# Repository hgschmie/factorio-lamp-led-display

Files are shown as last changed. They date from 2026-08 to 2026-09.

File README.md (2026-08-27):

# Factorio Lamp LED Display

Adds a mod to the Factorio game (2.1 version needed) that sends out UDP packets to a local receiver daemon. The daemon creates MQTT messages that can be picked up by embedded microcontrollers that in turn drive Neopixel LEDs which reflect the color and status of in-game Lamps.

Factorio -> UDP to local receiver -> daemon (golang code) -> MQTT (mosquitto broker) -> ESP32-C3 receiver -> Neopixel LEDs

This repository contains most of the pieces required to build this. You need to bring some skills/tools though:

- at least breadboarding, better soldering for the hardware
- a 3D printer to make the Lamp cases
- a local docker installation on the machine where you run Factorio (or you need to run the daemon manually, it is a single binary)

What you find:

- `daemon` contains the golang code for the local receiver daemon
- `factorio-mod` contains the code for the [Lamp LED Display](https://mods.factorio.com/mod/lamp_led_display) mod. Or get it from the mod portal
- `firmware` contains the software for the ESP32-C3 supermini board
- `pcb` contains the KiCAD files for a controller board. Or you can breadboard this together, either works fine.
- `3dprint` contains the 3MF files for the Lamp.

## How to get it to work

(All of this is intended to be run in a local network that is firewalled/secured against the internet. There is little security besides bare-bones passwords that are written in cleartext in config files locally. If you care deeply about security, there is room for improvement)

### Local setup

This sets up runtime config, broker credentials and starts the daemon.

```sh
cp config.example.yaml config.yaml
./scripts/create-credentials.sh
docker compose up -d --build
```

The `config.yaml` file is read by the daemon on startup. The secrets created by the script are stored in the `secrets` directory.

If everything goes well, this is what docker ps should show:

```text
❯ docker ps
CONTAINER ID   IMAGE                      COMMAND                  CREATED       STATUS       PORTS                                         NAMES
208767bb72bf   display-daemon             "/factorio-display"      6 hours ago   Up 6 hours   127.0.0.1:34198->34198/udp                    display-daemon-1
9c2e8b83e011   eclipse-mosquitto:2.0.22   "/docker-entrypoint.…"   6 hours ago   Up 6 hours   0.0.0.0:1883->1883/tcp, [::]:1883->1883/tcp   display-mosquitto-1
```

### Factorio Setup

- add the mod from the mod portal (or copy the `factorio-mod/lamp_led_display` folder into your mod folder). Add `--enable-lua-udp 34199` to the Factorio start command. If you run Factorio from Steam, you can add this to the "Launch Options" directly in Steam.

- Start Factorio and load a game that has the mod activated. Then run `docker logs -f display-daemon-1` from a command line window. You should see something like this:

```text
daemon-1     | {"time":"2026-08-27T01:00:59.183286626Z","level":"INFO","msg":"factorio packet accepted","save_id":"1f0288b3-4937613a","sequence":1,"type":"snapshot","channels":0}
```

If you see this, congrats, Factorio is talking to the locally running daemon and writes MQTT messages.

### Get some LEDs

Make sure to get an ESP32-C3 supermini board (most other ESP32-C3 boards should work, too).

- Install the PlatformIO framework. On a mac, do `brew install platformio`. Otherwise, go to [PlatformIO Core installation](https://platformio.org/install/cli) and follow the instructions

- connect your board to the computer with an USB cable

- run

```sh
cd firmware
pio run -e esp32-c3-supermini -t upload
pio device monitor
```

If all goes well, you should see a `Factorio-Display-xxxxxx` WiFi network appear. Connect to it (e.g. with a smartphone), it should pop open a capturing portal to enter WiFi credentials, MQTT broker information. Leave the pixel count as "8" and the "channel offset" as 0. Save, reboot and now the device should show (in the shell that does the `pio device monitor`) something like this:

```text
Connected!
*wm:AutoConnect: SUCCESS
*wm:STA IP Address: 172.16.10.102
Configuration page: http://172.16.10.102/ or http://factorio-display-shop-floor-a.local/
```

running `docker logs display-mosquitto-1` should show something like this:

```text
1787807093: New client connected from 192.168.65.1:46373 as factorio-display-shop-floor-a (p2, c1, k30, u'device').
```

### Assign a lamp

If you have any Neopixels connected to the ESP32-C3 chip, you are now ready to assign a lamp to them. If you are not running the game right now, after a few seconds, all LEDs should start to slowly pulse cyan to show that "no Factorio game is sending any information". This also happens when you pause the game.

Put a Lamp down, give it some color, make sure that "always on" is checked.

Press ALT/Option + Shift + D. The cursor should now show a lamp.

Click on the Lamp you just placed. In the dialog, set the Channel Number to "1". PRESS ENTER!

The first LED on your ESP32-C3 should now have the same color as the lamp in the game.

Press Control + Shift + D to open the Channel list where you can control other aspects or delete a channel.

----

## Project background

This project owes its existence to the lucky confluence of a few things.

- I found a Factorio Lamp on Makerworld that is designed for RGB (Neopixel) LEDs.
- I really wanted to play around with ESP32-C3 Supermini boards and I had a few lying around.
- Adafruit sells nice 5mm discrete multi-color LEDs that are Neopixel compatible.

And while all of this is great, some obstacles were in the way:

- The Factorio Lamp was single-color white and not gray/translucent. So some remixing was required.
- Besides 3D printing, this project requires some hardware and quite a bit of software.
- Firmware for the ESP32-C3
- Some daemon that takes UDP from Factorio and sends it to the board
- An actual Factorio mod that sends out UDP data messages.

That project was shelved for a year or so. Not much happened.

__If you are concerned about AI and can no longer sit back and allow AI infiltration, AI indoctrination, AI subversion and the international AI conspiracy to sap and impurify all of your precious bodily fluids, then this is the moment where you need to stop reading.__

----

I read [Matthew Brunelle's Blog](https://blog.matthewbrunelle.com/its-ok-to-use-coding-assistance-tools-to-revive-the-projects-you-never-were-going-to-finish/) and a new AI model arrived (GPT-5.6-sol if you are interested) and anyway, I wanted to find out how good AI really is.

I resurrected that project with a single prompt (typos and all):

```text
"here is what I want to do: I play the game factorio and I want to bring some of the aspects of the game to the real world. For that, I want to connect a few multi-color LEDs to a microcontroller, which can connect to WiFi. The factorio game should send some events out through its UDP interface to a local daemon (same host where the game runs) which in turn can turn these LEDs on and off.

I have a bunch of ESP-C3 microcontrollers, NeoPixel LEDs and passive components that would be needed to breadboard that together. I want to use the PlatformIO for the framework. The code on the ESP-C3 should allow me to configure WiFi when it boots up, then connect to a daemon running on my host using MQTT. In the long run, it should be possible to have multiple microcontrollers. The code on the microcontroller can be written in C or Rust, the daemon should be written in golang. If you have any questions, ask me, then create a plan on what we want to do."
```

~ 15 clarification questions and 20 Minutes later, I had about ~75% of this git repo. It went through a few iterations (some protocol additions, simplification of configuration, adding configuration pages to the microcontroller) afterwards.

And it worked on the first try.

It put together some documentation (the contents of the [docs folder](https://github.com/hgschmie/factorio-lamp-led-display/tree/main/docs) and the [README-codex](https://github.com/hgschmie/factorio-lamp-led-display/blob/main/README-codex.md)). None of those are 100% correct but pretty close.

What this project contains is not just AI generated code. I rewrote the factorio mod from scratch (the AI generated one was functional but ugly and iterating a few times made the code very convoluted) and while I got ChatGPT to put together ~50% of the PCB (KiCAD MCP is difficult to get to work but once it does, codex gets a lot done with it), I ultimately re-layouted it and routed it manually.

AI put together all of the tests (and updated them once I rewrote the factorio mod), the docker setup, all scripts and the docs. It verified the things I did and pointed out errors that I did not notice.

But I never touched (nor read) the ESP32-C3 firmware and the UDP daemon code. And the firmware has way more feature that I would have built myself (configuration pages! mDNS!). I assume the code is ugly for a human but so is the compiler output from a high level language compiler.

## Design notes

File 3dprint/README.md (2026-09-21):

# 3D Print files

These designs have been printed multiple times on a Bambu Lab X1 Carbon. If you use a different printer, load the 3MF files in your slicer and reslice them for your printer.

## Lamp

The lamps use the [Factorio lamp for a 5 mm LED](https://makerworld.com/en/models/3225142-factorio-lamp-for-5mm-led) design, with an opaque base and a translucent dome. The [lamp folder](lamp/) contains PETG and PLA 3MF projects and the assembled `lamp.stl` used in the base plate previews.

## Controller case

The [case](case/) houses the 55 × 55 mm controller PCB that drives up to eight lamps. Its outside dimensions are approximately **62.2 × 61 × 27 mm**.

The base has four PCB mounting posts for M3 self-tapping screws. A sliding lid runs in V-shaped grooves, with a window over the eight lamp headers for the four-wire cables. A separate opening in the side wall provides access to the controller's USB-C connector. The base and lid are designed to print without supports.

The OpenSCAD model is parameterized, and a small screw-fit test piece is available for checking the mounting-hole fit. See the [case README](case/README.md) for assembly, printing, calibration, and build instructions.

## Base plates

The [base plates](baseplate/) hold the lamps and controller case together. Three layouts are available:

| Layout | Lamps | Plate size | Printable file |
| --- | --- | --- | --- |
| Two rows of four, case behind the lamps | 8 | 200 × 180 mm | `baseplate/output/lamp-base-plate.stl` |
| Two rows of three, with two more lamps beside the case | 8 | 160 × 208 mm | `baseplate/output/lamp-base-plate-alternative.stl` |
| One row of three, with two more lamps beside the case | 5 | 160 × 160 mm | `baseplate/output/lamp-base-plate-five.stl` |

Each plate has shallow lamp recesses with small retaining lips and 14 × 7 mm cable slots offset toward one side of each lamp. The controller case clips into its mount **lid-down**, aligning its cable window with an opening in the plate. Six removable feet provide 10 mm of clearance for routing the wires underneath.

Use PETG for the plate and its clips. Feet are available in PETG or TPU 95A; use the **V2 TPU feet**, which have smaller, split retaining heads for easier insertion. Small lamp and box fit-test pieces are included.

There is also a thin glue-on cover for replacing a lamp at the specified position on the two-row-of-four plate if you make a mistake (or destroy an LED after you glued down a lamp and need to dremel it off the board.

See the [base plate README](baseplate/README.md) for fit tests, materials, dimensions, and the cover's intended position.

I ended up super-glueing the lamps to the base boards, once I confirmed that the LEDs work with the controller. Once you have glued them down, it is almost impossible to remove the lamps again. It really important to double-check the wire connections before powering on, flipping a connector by accident is a surefire way to kill the LED and then you have to hack off the lamp from the base board. I was trying to use a less destructive way (with the little retaining lips) but that did not work too well and I got bored and wanted to get this done.

## Generate the print files

With OpenSCAD on your PATH and Python 3 installed, run these commands from this directory:

```bash
make -C case OUT=out          # Case STLs and previews; refresh shared references
make -C baseplate             # All base plate parts, feet, and mesh validation
make -C baseplate previews    # Assembly and part previews
```

The case Makefile normally writes to `case/build/`; `OUT=out` writes to the `case/out/` location used by the base plate previews and clearance checks. Those previews also use `lamp/lamp.stl`. Base plate outputs go in `baseplate/output/`. Use `make -C baseplate everything` to build both printable parts and previews.

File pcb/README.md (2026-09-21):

# PCB

This directory contains the KiCad project for the eight-channel LED interface board and the LED adapter

## Interface Board (pcb folder)

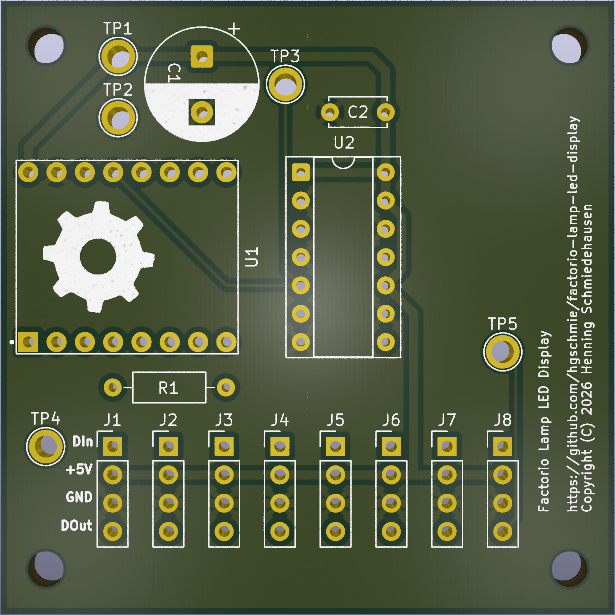
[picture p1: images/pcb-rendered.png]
KiCad rendered PCB Image


### Project files

- `pcb.kicad_pro`, `pcb.kicad_sch`, and `pcb.kicad_pcb` are the KiCad project, schematic, and board layout.
- `display_parts.kicad_sym`, `display_parts.pretty/`, `sym-lib-table`, and `fp-lib-table` are the project-local symbol and footprint libraries.
- `fabrication-toolkit-options.json` contains settings for the optional Fabrication Toolkit plugin.
- `production/` is generated output and is not an editable source of the design.

Open `pcb.kicad_pro` in KiCad. Use the Schematic Editor to change the circuit, then run **Inspect → Electrical Rules Checker**. Transfer changes with **Tools → Update PCB from Schematic**, finish placement and routing in the PCB Editor, refill copper zones, and run **Inspect → Design Rules Checker**. Resolve all DRC errors before ordering.

### Creating fabrication files

Save the project before exporting. In the PCB Editor, use **File → Fabrication Outputs** to create:

- Gerbers for `F.Cu`, `B.Cu`, `F.Mask`, `B.Mask`, `F.Silkscreen`, `B.Silkscreen`, and `Edge.Cuts`;
- separate plated and non-plated Excellon drill files;
- paste layers only when ordering a solder stencil;
- a BOM and component-position file only when ordering assembly.

Alternatively, if the Fabrication Toolkit plugin is installed, run it from **Tools → External Plugins** and export into `production/`. Zip the Gerber and drill files together and upload that archive to the PCB manufacturer. Check the manufacturer's Gerber preview, board dimensions, layer count, thickness, and drill holes before placing the order.

KiCad lock files, `pcb-backups/`, `*.kicad_prl`, exported netlists, and files under `production/` are generated or machine-local and do not need to be committed.

## LED Board (led folder)

Soldering the LEDs to wires became cumbersome so I designed another, small board. I ordered 50 of those from both JLCPCB and PCBWAY (and I paid more for shipping than the actual boards).

I used LEDs from adafruit (https://www.adafruit.com/product/1938) but they are expensive and often out of stock. Those can be used with the board but DIn and DOut are swapped compared to the board print. Also, make sure that the ground pin (inner short pin) really is in the right place on the board. These LEDs use RGB order, so the controller must be set accordingly.

I used *WAY MORE* shockingly cheap (~$.24 compared to roughly $1 from adafruit) LEDs from Amazon (https://www.amazon.com/dp/B0H87Y196Q). While it looked a bit shady, they came straight from China (8 business days) and work fine. Two caveats, however: a) They have a different color order (GRB). This can be configured on the controller but it means you can not mix with adafruit LEDs. And b) more importantly, those LEDs are really sensitive to be wired up wrong. Almost any LED I ever used can survive a brief wiring error but not those. One mistake and the LED is toast. Double check your connections and order more than the few you need (I mean, they come in 100 packs) because you will fry a few (I fried about a dozen).

The boards show a wire connector but in reality there is not enough space below the 3d printed LED case for that. Solder the wires directly to the board.

Speaking of wires:

Unless you really like crimping dupont connectors (I don't), making the connectors for the LEDs is pretty annoying. I ended up buying breadboard jumper cables (https://www.amazon.com/dp/B0FJXZZM83) and cut off the connectors on one side and soldered them directly onto the LED boards. That leaves you with the problem of four separate, small pins one the other end which are annoying to plug onto the controller board (especially through the opening in the top of the box or the underside of a base plate. Enter https://makerworld.com/en/models/2594713-dupont-connector-bridge which is fantastic for turning four pins into a single connector (with a pin 1 marker! That is really important, see above). Except that it is a tiny bit too tall to fit eight in a row onto the board (if I had discovered those before I ordered the boards, I would have left more space but I did not). So I asked claude to make a slimmer version, which is in the `3dprint/connector` folder.

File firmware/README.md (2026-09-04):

# ESP32-C3 NeoPixel controller firmware

This firmware receives the retained 64-channel MQTT frame from the Factorio display daemon and renders a configured consecutive range on locally attached NeoPixels. It targets an ESP32-C3 SuperMini using the Arduino framework and PlatformIO.

The controller stores its network, MQTT, and channel configuration in non-volatile storage. Initial setup uses a captive portal; MQTT and display settings can subsequently be changed through a normal web page on the trusted LAN.

See [the protocol reference](../docs/protocol.md) for MQTT payloads and topics, and [the wiring guide](../docs/wiring.md) before connecting LEDs.

## Hardware target

- ESP32-C3 SuperMini, built through PlatformIO's `esp32-c3-devkitm-1` board definition.
- GPIO4: 800 kHz NeoPixel data output.
- GPIO9: onboard BOOT button, monitored for provisioning requests.
- Between 1 and 16 RGB NeoPixels in firmware; the project PCB exposes eight connectors.
- `RGB` and `GRB` byte order support.
- USB CDC serial console at 115200 baud.
- USB-only firmware installation; OTA updates are not implemented.

GPIO4 must feed the LEDs through the 74AHCT125 level shifter and series resistor described in the wiring guide. Do not connect a 5 V NeoPixel data input directly to the ESP pin.

## Build dependencies

Install [PlatformIO Core](https://docs.platformio.org/en/latest/core/installation/index.html) or use the PlatformIO IDE extension. PlatformIO downloads the Espressif toolchain, Arduino framework, and pinned libraries automatically.

The embedded environment is defined in `platformio.ini`:

| Component | Version |
| --- | ---: |
| PlatformIO Espressif 32 platform | `6.10.0` |
| Arduino framework | supplied by the platform |
| PubSubClient | `2.8` |
| WiFiManager | `2.0.17` |
| ArduinoJson | `7.3.1` |
| Adafruit NeoPixel | `1.12.5` |
| Firmware version reported in telemetry | `2.0.2` |

The native parser tests additionally require a host C++ compiler supported by PlatformIO. Unity is selected as the test framework.

## Build, flash, and monitor

Run commands from the `firmware` directory:

```sh
pio run -e esp32-c3-supermini
pio run -e esp32-c3-supermini -t upload
pio device monitor -b 115200
```

The first command compiles without flashing. The firmware binary is normally written beneath:

```text
.pio/build/esp32-c3-supermini/
```

If PlatformIO cannot choose the serial device automatically, provide it explicitly:

```sh
pio run -e esp32-c3-supermini -t upload --upload-port /dev/cu.usbmodemXXXX
pio device monitor --port /dev/cu.usbmodemXXXX -b 115200
```

The exact device name varies by operating system and USB connection. The build enables USB CDC on boot and uses DIO flash mode.

From the repository root, the equivalent build target is:

```sh
make build-firmware
```

## Tests

Run the host-native frame-parser tests without an ESP:

```sh
cd firmware
PLATFORMIO_CORE_DIR=.pio-core pio test -e native
```

Or, from the repository root:

```sh
make test-firmware
```

The tests cover configured channel extraction, default and explicit brightness, effects, sequence rejection, channel-range bounds, complete-frame enforcement, duplicate channels, invalid protocol versions, expiry, atomic rejection, and connection-state transitions.

## First boot and captive provisioning

At startup the firmware loads saved settings and asks WiFiManager to connect using saved Wi-Fi credentials. If there are no credentials or the connection fails, it starts a captive portal.

1. Power the ESP32-C3 over USB.
2. Join the Wi-Fi network named `Factorio-Display-<chip-id>`.
3. If the portal does not open automatically, visit `http://192.168.4.1/`.
4. Select the target Wi-Fi network and enter its password.
5. Save and allow the controller to join the selected Wi-Fi network.
6. From a computer on that network, open the normal management page and configure MQTT and display settings.

The captive portal configures Wi-Fi only and each session times out after five minutes. If connection fails, the firmware waits one second and retries the Wi-Fi provisioning flow. MQTT and display settings are deliberately kept on the normal management page, where they are easier to enter from a computer.

Until the management configuration is saved, the controller uses these defaults:

| Field | Default |
| --- | --- |
| Device ID | `esp-<chip-id>` |
| MQTT port | `1883` |
| Pixel count | `8` |
| Channel offset | `0` |
| Pixel color order | `RGB` |

MQTT remains disabled until a valid broker is saved through the management page. The broker field is passed directly to the Arduino MQTT client. Enter only a hostname or IP address, such as `192.168.1.20`; do not enter a URL such as `tcp://192.168.1.20:1883`. The port has its own field. When Mosquitto runs through Docker Compose, use the Docker host's LAN address, not the internal service name `mosquitto`.

The device ID becomes part of the MQTT client ID, availability topic, telemetry topic, and mDNS hostname. Give every controller a unique ID.

### Pixel count and channel offset

The daemon publishes 64 global channels numbered `0..63`. Each controller extracts a consecutive local range:

```text
local pixel 0 = global channel offset
local pixel n = global channel offset + n
```

The configuration must satisfy:

```text
1 <= pixel_count <= 16
0 <= channel_offset <= 63
channel_offset + pixel_count <= 64
```

For two eight-pixel controllers:

| Controller | Pixel count | Offset | Global channels |
| --- | ---: | ---: | --- |
| First | 8 | 0 | `0..7` |
| Second | 8 | 8 | `8..15` |

Factorio's assignment interface is one-based, so global MQTT channel `0` corresponds to Factorio lamp channel `1`.

## Re-entering the captive portal

Hold the onboard BOOT button continuously for five seconds while the firmware is running. The background button monitor sets a provisioning request independently of MQTT connection attempts. The main loop then:

1. Stops the normal management server and mDNS.
2. Publishes `offline` and disconnects MQTT when connected.
3. Starts the `Factorio-Display-<chip-id>` captive portal.
4. Restarts the ESP after provisioning completes or times out.

Use this portal when Wi-Fi credentials need to change. Holding BOOT during reset can select the ESP ROM bootloader; wait until the firmware is running before beginning the five-second hold.

## Normal management page

After the ESP joins Wi-Fi, it starts an HTTP server on port 80 and advertises it over mDNS. Open either address shown on the serial console:

```text
http://<controller-ip>/
http://factorio-display-<device-id>.local/
```

The mDNS name is lowercase. Characters other than letters, digits, and hyphens are replaced with hyphens. If `.local` discovery is unavailable on the client network, use the numeric IP address.

The page displays the controller's IP address and current MQTT connected/disconnected state. It can change:

- MQTT broker host and port.
- MQTT username and password.
- Device ID.
- Pixel count and channel offset.
- `RGB` or `GRB` pixel order.

The stored MQTT password is never displayed on this page. Leave the password field empty to retain it; enter a value to replace it. Submitted values are validated as a complete configuration before they are written.

After a successful save, the ESP sends a confirmation page, waits approximately 300 ms, and restarts. The confirmation page attempts to return to `/` after ten seconds, once the controller has rejoined Wi-Fi.

The normal management page does **not** edit Wi-Fi SSID or password. Use the five-second BOOT procedure to return to the captive portal for Wi-Fi changes.

Unknown HTTP paths redirect to `/`. There is no HTTP authentication or TLS, so expose this page only on a trusted LAN.

## MQTT operation

The firmware uses a fixed protocol prefix and subscribes to the retained global frame at QoS 1:

```text
factorio-display/v2/channels/set
```

It connects with client ID:

```text
factorio-display-<device-id>
```

Connection behavior:

- MQTT is attempted immediately and retried every five seconds after failure.
- Wi-Fi power saving is disabled for connection stability. After a Wi-Fi loss, the controller explicitly retries every five seconds and reconnects MQTT as soon as an IP address is restored.
- If Wi-Fi remains unavailable for 60 seconds, the controller restarts. The normal startup provisioning behavior applies if the network is still unavailable.
- Keepalive is 30 seconds and socket timeout is two seconds.
- The MQTT packet buffer is enlarged to 8192 bytes for the complete 64-channel frame.
- Reconnecting resets the local sequence baseline and waits for the broker's retained frame.
- The Last Will is retained `offline` at QoS 1.
- A successful connection publishes retained `online` and subscribes to the frame topic.

Availability and telemetry topics are device-specific:

```text
factorio-display/v2/device/<device-id>/availability
factorio-display/v2/device/<device-id>/telemetry
```

Telemetry is non-retained and published every 30 seconds. It contains protocol version, firmware version, IP address, RSSI, uptime, pixel count, channel offset, and pixel order.

MQTT uses plain TCP without TLS. The broker credentials and management page are suitable only for a trusted network.

The captive provisioning access point is also created without an AP password. Start it only in a trusted physical environment and close provisioning promptly after saving the configuration.

## Frame validation

Frames are accepted atomically: a malformed message never partially changes the displayed pixels. A valid frame must have:

- Protocol version `2`.
- A sequence larger than the last accepted sequence in the current MQTT session.
- Relative expiry from `1` through `60000` ms.
- Exactly 64 unique channel records covering `0..63`.
- RGB values in `0..255`.
- Optional brightness in `0..255`; omitted brightness defaults to `255`.
- Effect `solid`, `blink`, or `pulse`.

Only the configured range is copied into the local frame after the complete global message validates. Rejection reasons are printed to the serial console as `Rejected MQTT frame: ...`.

## LED behavior

| State | Display |
| --- | --- |
| MQTT disconnected | Amber breathing pattern on every configured pixel |
| MQTT connected, no accepted frame | Black |
| Last accepted frame expired | Black |
| Active frame | Per-channel RGB, brightness, and effect |

`solid` holds the configured value. `blink` alternates on/off every 500 ms. `pulse` applies a smooth sine-wave brightness modulation. Per-channel brightness is applied in software across the complete `0..255` range; the NeoPixel library's global brightness remains at full scale.

Factorio staleness is represented by a normal daemon-generated frame—cyan pulse by default—so it remains visually distinct from both MQTT-disconnected amber and connected-without-frame black.

Pixel order defaults to `RGB`. If a green command produces red, or colors otherwise appear swapped, change the controller to `GRB` through the management page.

## Persistent settings

MQTT and display values are stored with Arduino `Preferences` in the NVS namespace `display`. Stored values are:

- Broker host and port.
- MQTT username and password.
- Device ID.
- Pixel count and channel offset.
- Pixel color order.

WiFiManager/ESP Wi-Fi storage retains the Wi-Fi SSID and password separately. Flashing a new firmware image normally does not erase NVS; an explicit full-flash erase is required to remove all saved configuration.

## Troubleshooting

- **No serial port appears:** use a data-capable USB cable, reconnect the board, and check PlatformIO's device list with `pio device list`.
- **Upload cannot connect:** select the correct upload port. If necessary, use the board's BOOT/reset procedure to enter the ROM bootloader, then retry.
- **Captive portal does not appear:** hold BOOT for five seconds after the firmware is running, reconnect to the `Factorio-Display-<chip-id>` access point, and browse to `192.168.4.1`.
- **Wi-Fi works but MQTT authentication fails:** open the normal management page and replace the MQTT password. The `device` password is different from the daemon password.
- **MQTT broker is unreachable:** use the Docker host's LAN IP, not `localhost`, `mosquitto`, or a `tcp://` URL.
- **LEDs breathe amber:** MQTT or Wi-Fi is disconnected. The controller retries Wi-Fi and MQTT automatically and restarts after 60 seconds without Wi-Fi. Check the serial log, broker address, credentials, Mosquitto ACLs, signal strength, and LAN reachability.
- **LEDs remain black:** MQTT is connected, but no complete unexpired frame has been accepted. Inspect daemon logs and the serial console.
- **LEDs show cyan pulse:** the controller is operating, but the daemon considers Factorio stale.
- **Wrong LEDs are addressed:** verify pixel count and channel offset, remembering that Factorio channels are one-based while MQTT channels are zero-based.
- **Colors are swapped:** change `RGB`/`GRB` pixel order.
- **Frames are rejected as stale:** confirm the daemon is publishing increasing sequences. An MQTT reconnect resets the controller's sequence baseline.

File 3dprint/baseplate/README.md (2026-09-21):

# Eight-lamp base plate

Reference models are shared with the neighboring projects: `../case/out/base.stl`, `../case/out/lid.stl`, and `../lamp/lamp.stl` (paths relative to this folder). Previews and clearance checks use these files; the printable baseplate geometry does not depend on importing them.

## Build with make

Run **`make`** in this folder to create all current printable STLs in `output/`: the three plates, glue-on cover, PETG and TPU V2 feet, and fit-test pieces. It also validates all meshes and writes `output/mesh-checks.json`. Builds are incremental, including dependencies on the shared SCAD source.

```bash
make                 # Printable files plus mesh validation
make previews        # Current PNG previews
make everything      # Printable files, validation, and previews
make -B              # Force a rebuild of printable files
make clean           # Remove only Makefile-managed generated files
```

The Makefile defaults to `openscad` on your PATH and `python3` (standard library only). Override them if needed: `make OPENSCAD=/path/to/openscad PYTHON=python3`. Source STL/3MF files, archived versions, and historical comparison images are preserved by `make clean`. When running through the Codex sandbox on this machine, OpenSCAD needs outside-sandbox execution; ordinary Terminal use requires no special flag.

## Small lamp-retaining lips

Both plate layouts and `output/lamp-fit-test.stl` now include retaining lips rising **1.5 mm above the deck**. They are 1 mm thick, move inward 0.3 mm to take up 0.6 mm of total sideways play, and have a 0.2 mm inward bead with a beveled insertion ramp. The small bead is intended to give a press-in grip; it creates up to approximately 0.15 mm nominal local interference with the source lamp's vertical outer details. The grip and insertion force require a new physical test.

For each lamp, the two sides away from the box have full-length lips. The other two sides have half-length lips anchored at the far corners, leaving the corner toward the box open. The direction is calculated from each lamp center to the box center, so it is mirrored appropriately across both layouts. The shifted cable slot remains in place.

Print the revised lamp test in PETG before printing a full plate. Press the lamp in gently and check retention and removal. If the bead is too tight, reduce `lamp_lip_bead` (currently 0.2 mm); adjust `lamp_lip_inset` for sideways fit. The box clips are unchanged. The TPU foot insertion problem is addressed by the V2 feet described below. Render colors only distinguish surfaces; each plate is one printed part.

## Lamp cable-slot revision after test printing

The box clip has been reported to fit successfully; the later TPU feet were too difficult to insert and have been revised below. The lamp cable slot has now moved **10 mm toward +Y** from each lamp center, retaining its 14 × 7 mm dimensions. +Y is upward in the top-view comparison and alternative-layout top view; the same lamp-relative direction is used on both plates. On the 48 mm lamp test piece, the hole center moves from (24,24) to (24,34) mm. The new location still has approximately 5.8 mm of recess floor between the slot and the nearby recess wall.

Both full plate STLs and `output/lamp-fit-test.stl` include this revision. `output/lamp-slot-comparison.png` shows the old and new positions; the dashed orange outline marks the former centered hole on the new test piece. The revised cable alignment still needs to be checked against the actual lamp. Adjust `lamp_hole_offset` in the shared SCAD source to change direction or distance. Copies of the previous centered-slot STLs are in `reference/centered-slot/`.

## Alternative layout: 3 + 3 + 2

`output/lamp-base-plate-alternative.stl` is a 160 × 208 mm portrait plate matching this top-view arrangement:

```text
lamp   lamp   lamp
lamp   lamp   lamp
lamp   +---------+
lamp   |   box   |
       +---------+
```

The lamps remain on a 48 mm grid. The lower-right box is centered vertically beside the bottom two lamps, lid-down, with its side connector facing the outer right edge. Its aligned 44 × 17 mm cable opening is centered at (111.4, 39.69) mm. Recesses, slots, deck thickness and retaining clips are reused from the first design. The same six TPU 95A feet fit sockets along the two side edges; no new feet or fit-test parts are needed.

Edit `lamp-base-plate-alternative.scad` to change this layout; keep `lamp-base-plate.scad` beside it because it supplies the shared geometry. Preview images are `output/alternative-top.png` and `output/alternative-assembly.png`. The original layout remains available separately.

The alternative STL passed closed-edge and connected-solid checks. The box and foot mountings retain their existing geometry. The lamp bead now intentionally introduces a small press-fit interference, so the earlier clearance-only checks for lamps are no longer acceptance criteria. Physical retention must be checked with the revised lamp test.

```bash
/opt/homebrew/bin/openscad -o output/lamp-base-plate-alternative.stl --export-format binstl lamp-base-plate-alternative.scad
```

## Third layout: five lamps

`output/lamp-base-plate-five.stl` is the shorter **160 × 160 mm** version of the second plate. Its top row of three lamps has been removed and the plate shortened by 48 mm. It retains one row of three above the box and two down the box's left side:

```text
lamp   lamp   lamp
lamp   +---------+
lamp   |   box   |
       +---------+
```

The remaining lamp centers, 1.5 mm retaining lips, off-center cable slots, inverted box mount, and side-facing connector orientation match the second plate. It uses the same six TPU V2 feet; foot sockets are repositioned along the shorter side edges. The first two plates remain separate and unchanged.

Source: `lamp-base-plate-five.scad` (requires the shared `lamp-base-plate.scad` beside it). Previews: `output/five-top.png` and `output/five-assembly.png`.

```bash
/opt/homebrew/bin/openscad -o output/lamp-base-plate-five.stl --export-format binstl lamp-base-plate-five.scad
```

## Print files

### Glue-on replacement-lamp cover

`output/lamp-position-cover.stl` is a **43.36 × 43.566 × 1.2 mm** flat cover for the first 2×4 board's near-box row, second lamp from the left in the delivered front view. The user confirmed the retaining lips at this position have been removed. The cover overlaps the recess by 2.5 mm on each side, except at the small curved corner notch that clears the adjacent central foot head.

The 14 × 7 mm rounded wire slot matches the existing slot, offset 10 mm from the lamp center. When installed, the notch points toward the nearby foot at the upper-right corner and the cable slot lies on the opposite half, away from the box. The notch radius is 4.2 mm, giving at least 0.7 mm nominal radial clearance around even the original 7 mm TPU head; clearance is larger around the current V2 head.

Print flat, either broad face down, with no supports. Dry-fit with the cable slot aligned and the notch around the foot, then glue the overlapping border to the board. The upper surface is flat for attaching the replacement lamp. A lamp placed on the cover will sit approximately 2.6 mm higher than one seated in the original recess, plus glue thickness.

Source: `lamp-position-cover.scad`. Preview: `output/lamp-position-cover-detail.png`. The cover passed closed-mesh checks and a digital collision check against the board with this position's lips removed and a conservative 7 mm foot-head envelope. The original board STLs are unchanged.

```bash
/opt/homebrew/bin/openscad -o output/lamp-position-cover.stl --export-format binstl lamp-position-cover.scad
```

### Base plates and test pieces

- `output/lamp-base-plate.stl`: main plate, 200 × 180 mm; 4 mm deck; tallest clip 33.30 mm above the underside.
- `output/feet.stl`: all six removable snap-in feet, providing 10 mm of clearance below the plate.
- `output/foot.stl`: one foot for a trial print or replacement.
- `output/lamp-fit-test.stl`: one lamp recess and cable slot, 48 × 48 mm.
- `output/box-fit-test.stl`: full-size box cradle with both clips and a foot socket, 84 × 80 mm.
- `output/assembly.png`: assembled reference view using the supplied lamp and enclosure meshes.
- `lamp-base-plate.scad`: editable, parameterized source. Set `part` to select a print part or the assembly preview.

The assembly preview is not a printable combined model. Print only the plate and feet; use the existing lamp and enclosure designs separately.

## Fit and wiring

### TPU 95A feet option

Use **`output/feet-tpu95a-v2.stl`** for six revised TPU 95A feet, or **`output/foot-tpu95a-v2.stl`** for one trial foot. The unversioned TPU STL names also contain V2. These replace the PETG feet and fit the same plate sockets, with the same 14 mm base diameter and nominal 10 mm clearance. Keep the plate and its box clips in PETG.

The original solid 7 mm head proved too difficult to insert. V2 reduces the head to 6.2 mm and the stem to 5.2 mm, and adds a 1.2 mm-wide compression slot through the head and stem, ending 1.5 mm into the foot body. This creates two broad halves that can flex inward through the nominal 5.8 mm socket. The narrower lead-in is 4.2 mm. Plate holes and the 14 mm foot base / 10 mm standing height are unchanged, so no plate reprint is needed. Original failed foot meshes are archived in `reference/tpu-v1/`.

Print broad end down with your TPU 95A profile. Preserve the compression slot: confirm it is open in the slicer preview and clear any stringing after printing. No supports are intended. Press the tapered head through the socket until the broad foot sits against the underside and the head expands above the plate.

Print one V2 foot first and try it in the actual printed plate. Check insertion, full seating, and resistance to pulling out or rocking before printing all six. V2 meshes passed closure checks, but insertion force and retention are not physically verified. If it still will not insert, measure the actual printed hole and head before further adjustment. Remove by squeezing the two halves together from above and easing the head back through the hole.

```bash
/opt/homebrew/bin/openscad -o output/foot-tpu95a.stl --export-format binstl -D 'part="foot"' -D 'foot_material="TPU95A"' lamp-base-plate.scad
/opt/homebrew/bin/openscad -o output/feet-tpu95a.stl --export-format binstl -D 'part="feet"' -D 'foot_material="TPU95A"' lamp-base-plate.scad
```

### Layout and PETG feet

Eight lamps sit on 48 mm centers in two rows of four. Each recess is 38.36 × 38.566 mm and 1.4 mm deep, with 0.35 mm nominal clearance per side around the source lamp's bounding footprint. The floor is 2.6 mm thick. A rounded 14 × 7 mm through-slot beneath each lamp allows a four-pin connector to be fed upward into the lamp's open underside. Check your actual connector, including any heat-shrink or sleeve, in the test piece.

The enclosure sits centered behind the lamps, upside down with its lid toward the plate. Rotate it 180° about its left-to-right axis: the large lid cable opening faces the lamp rows; the existing side connector port faces the left edge of the plate when viewed from the lamps. Its original top rails and lid lip rest on the plate. The matching 44 × 17 mm through-opening is at plate coordinates (100.6, 55.81), aligned with the source lid opening (approximately 41.54 × 14.16 mm).

Two PETG cantilever clips catch the enclosure's upper edge (its original bottom). Four low corner guides locate it. The clips have 0.35 mm side clearance, 0.8 mm nominal overlap, and about 0.3 mm vertical clearance. Press the outward tabs away from the enclosure to release it; remove the enclosure before sliding the lid. Leave enough cable slack to lift it for service. The existing side connector port is clear of the clips.

Wires run freely beneath the raised plate. Feed connectors upward through the lamp slots and downward through the box opening, one at a time. No connectors need to pass through a closed cable tunnel. The design does not add cable clamps or strain relief; retain those at the lamp/box as required by your existing assembly.

Six feet push in from below. Their split pegs snap through the round sockets and remain visible on the top face. To remove a foot, gently compress its prongs from above while pulling it down. Feet need no screws or glue.

## Print and assembly

Use PETG for the clips and snap feet. Suggested starting settings: 0.4 mm nozzle, 0.2 mm layers, four perimeters, five top/bottom layers, and 25% infill. Place all supplied STL files flat as exported. The main plate has a flat underside; feet print broad end down. The only small unsupported details are the clip hook ledges and foot collars; support-free printing is intended but should be checked in the slicer and on the test pieces. Use a brim if needed for the large plate.

1. Print the lamp test, box test, and one foot with the intended material and settings.
2. Check lamp insertion/removal, connector passage, box seating, clip engagement/release, and foot engagement. Clips must flex without cracking or forcing the enclosure.
3. If needed, adjust `lamp_clearance`, `box_clearance`, `clip_overlap`, or the foot diameters in the SCAD source, then re-export and retest.
4. Print the full plate and six feet. Fit the feet, route the cables, seat the lamps, and gently snap in the inverted enclosure.

The model has been checked digitally for mesh closure. The user has confirmed that the printed box clip works; the original solid-head TPU feet failed insertion and have been replaced with the V2 design below. The lamp-retaining bead and off-center cable slot need a physical fit check before committing to the full plate.

## Regenerate

Run from this directory, using the command-line OpenSCAD installation:

```bash
/opt/homebrew/bin/openscad -o output/lamp-base-plate.stl --export-format binstl lamp-base-plate.scad
/opt/homebrew/bin/openscad -o output/feet.stl --export-format binstl -D 'part="feet"' lamp-base-plate.scad
/opt/homebrew/bin/openscad -o output/foot.stl --export-format binstl -D 'part="foot"' lamp-base-plate.scad
/opt/homebrew/bin/openscad -o output/lamp-fit-test.stl --export-format binstl -D 'part="lamp_test"' lamp-base-plate.scad
/opt/homebrew/bin/openscad -o output/box-fit-test.stl --export-format binstl -D 'part="box_test"' lamp-base-plate.scad
python3 reference/verify_meshes.py
```

The shared lamp STL is imported as a single mesh for previews and clearance checks. Its corner-based coordinates are shifted by (-18.83, -18.933, 0) mm to align it with the centered lamp seats; its bottom remains at Z=0. STL does not retain the former multi-part color assignments, so the lamp preview is a single color. The older extracted component STLs in `reference/` are retained as historical assets and are no longer build dependencies. `reference/check-clearance.scad` contains checks for the default dimensions; update its fixed placements if the layout is changed. OpenSCAD may return zero-thickness contact faces for these checks; those are distinguished from positive-volume interference.

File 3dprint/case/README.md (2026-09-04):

# Enclosure for the lamp-led-display PCB

Parametric OpenSCAD sliding-lid box for the 55 x 55 mm board (ESP32-C3 SuperMini on a socket,
74AHCT125, 1000 uF cap, eight 1x4 LED headers).

## Files

| file | purpose |
|---|---|
| `case.scad` | the model. Open in OpenSCAD; pick `part` in the Customizer (base / lid / board / assembly / exploded / section / screw_test) |
| `board_data.scad` | board outline, holes, headers and component courtyards, **generated** from `../../pcb/pcb/pcb.kicad_pcb` |
| `kicad2scad.py` | the generator: `uv run kicad2scad.py ../../pcb/pcb/pcb.kicad_pcb board_data.scad` |
| `test_case.py` | fit tests: `uv run test_case.py` renders the STLs and checks them against the board data |
| `Makefile` | `make` builds `build/base.stl`, `build/lid.stl` and previews; `make test`; `make board_data` |
| `build/base.stl`, `build/lid.stl` | ready to slice (git-ignored, rebuild with `make`) |

Both Python scripts carry inline dependency metadata, so the only tool you need is
[uv](https://docs.astral.sh/uv/) (`brew install uv`); it creates a throwaway environment on first run.
OpenSCAD has to be on `PATH` (or set `OPENSCAD=/Applications/OpenSCAD.app/Contents/MacOS/OpenSCAD`).

## Design

* Outer size 62.2 x 61 x 27.0 mm, walls 2.5 mm, floor 2 mm.
* Board sits on four 6.5 mm standoffs (4 mm tall) over its M3 holes, with blind pilot holes for M3
  self-tapping screws (M3 x 6 works; 4.4 mm of thread engages below the PCB, 1 mm of floor is left intact).
  `screw_hole_d` is the diameter **as measured on the print**: FDM cuts vertical holes undersized, so the model
  adds `hole_comp` on top of it. The shipped 2.8 mm was measured on a Bambu X1C with the coupon below;
  recalibrate rather than guess if your printer or filament differs.
* Lid (2 mm) slides in from the back edge (the edge away from the LED headers). Its left, right and front
  edges are chamfered top and bottom at 45 degrees to a V (0.4 mm flat at the tip) that runs in a matching V groove
  in the walls (1.2 mm deep, 0.3 mm gap to every flank). All groove faces are 45 degrees or steeper, so neither
  part needs support, and the lid centres itself in the grooves instead of binding on a flat ceiling.
* A full-width bar on the lid's rear edge (same rounded corners as the case) fills the recess in the back wall
  flush with the wall tops and seats against the side walls as the end stop, so the closed box has a continuous
  back face.
* Window in the lid over J1..J8 so Dupont cables plug in from the top.
* USB-C opening (13 x 6.7 mm) in the left wall, centred on the ESP32 module. The receptacle's lower edge is
  2.9 mm above the PCB and it sticks out 1 mm past the board edge, so the left wall is pushed out by 1.2 mm
  and the board still drops straight in; the receptacle ends up flush with the inner wall face, inside the opening.
* Height budget: tallest part (C1) measured 14 mm above the PCB, plus 1.5 mm air.

## Things to tune after the first print (all at the top of `case.scad`)

* `max_part_h` -- C1 height above the PCB (14 mm measured). Every mm changes the case height directly.
* `usb_z0`, `usb_overhang` -- USB-C lower edge above the PCB (2.9) and how far it sticks out past the board edge (1.0).
* `lid_clear` -- gap between the lid's V edge and every groove flank. Lid too tight: +0.05; lid rattles: -0.05.
* `lid_tip` -- flat at the tip of the V edge (0.4 mm = two layers). Larger makes the edge sturdier and the groove deeper.
* `board_clear` -- board should drop in without force; the 0.5 mm default suits most printers.
* `screw_hole_d` / `hole_comp` -- the printed pilot diameter and the printer's hole shrinkage. Print
  `part=screw_test` (a 5 minute coupon with one real-size boss per labelled diameter), drive an M3
  self-tapping screw into each, and copy the label of the boss that bites firmly without needing much torque
  into `screw_hole_d`. Screws too loose: go a step down; too hard to drive or the boss splits: a step up.

## Printing

* Base: as modelled, open side up. No supports: the groove flanks are 45 degrees, the USB opening is a 13 mm bridge.
* Lid: as modelled, flat underside on the bed, rear bar up. No supports; the lower V flanks are 45 degree overhangs.
* Do not enable supports in the slicer for either part; the V grooves are exactly where support is hard to remove.
* Calibration coupon: `make build/screw_test.stl`, print flat, no supports. Takes about 5 minutes and a gram
  of filament, and saves reprinting the whole base to find the pilot diameter.
* 0.2 mm layers, 3 walls, 20 % infill is plenty.

## Workflow

1. Change the PCB in KiCad -> `make board_data` -> `make test` -> `make`.
2. Tweak parameters -> `make test` -> `make`. `part=section` in the Customizer shows the V edge sitting in the groove.
3. New printer or filament -> `make build/screw_test.stl`, print it, set `screw_hole_d` from the result.

The tests check that the PCB and every component courtyard clear the base, standoffs sit exactly under
each hole, the whole lid (plate, V edges, bar) can be swept along its slide path without hitting anything,
the grooves actually hold the lid down, the back face is closed when the lid is in, no face of either part
overhangs by more than 45 degrees (no supports), the lid window clears all eight headers, the USB opening is
open where the module is, the pilot holes carry the shrinkage compensation and stay blind with enough wall
around them, the coupon matches the real boss, and both meshes are watertight.

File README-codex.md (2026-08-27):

# Lamp LED Display

This monorepo mirrors circuit-controlled Factorio 2.1 lamps on physical NeoPixels. The Factorio mod reports up to 64 lamp channels over localhost UDP, the Go daemon converts them into a retained global MQTT frame, and each ESP32-C3 controller displays a configured slice of that frame.

```text
Factorio lamps ── UDP 127.0.0.1:34198 ──► Go daemon ── MQTT ──► ESP32-C3 ──► NeoPixels
```

The current mod is lamp-only. It does not monitor crafting machines and does not add a separate lamp entity; it assigns ordinary Factorio lamps, including compatible lamps supplied by other mods.

## Quick start

Requirements are Factorio 2.1, Docker with Compose, PlatformIO, an ESP32-C3 SuperMini, a 74AHCT125-compatible level shifter, and the parts described in [the wiring guide](docs/wiring.md).

### 1. Start Mosquitto and the daemon

Create the local configuration and separate credentials for the daemon and devices:

```sh
cp config.example.yaml config.yaml
./scripts/create-credentials.sh
docker compose up -d --build
```

The credentials script prompts for two passwords. It creates the `daemon` and `device` Mosquitto users, stores the daemon credentials in Compose secrets, and writes the device password to `secrets/device_password` for use during controller provisioning. These generated files and `config.yaml` are ignored by Git.

Docker publishes the daemon's UDP receiver only on host loopback at port `34198`. Mosquitto port `1883` is exposed on all host interfaces so controllers on the LAN can connect. MQTT is authenticated but unencrypted; use it only on a trusted network.

`config.yaml` contains the MQTT broker/client settings and all daemon status colors. The `factorio-display/v2` prefix is fixed for protocol version 2. Color changes are checked every second and hot-reloaded only after the complete YAML file validates. An invalid reload leaves the previous configuration active. Changing the broker or client ID requires a daemon restart.

### 2. Install and configure the Factorio mod

Copy `factorio-mod/lamp_led_display` into the Factorio mods directory and enable **Lamp LED Display**. Launch Factorio with Lua UDP enabled; on macOS:

```sh
/Applications/factorio.app/Contents/MacOS/factorio --enable-lua-udp 34199
```

Port `34199` is Factorio's Lua UDP port and must be available. The mod's startup setting targets the daemon on port `34198`; the two port numbers are intentionally different.

After lamp technology is available:

- Use the toolbar shortcut or Alt+Shift+D, select exactly one lamp, and enter a channel from `1` through `64`.
- Set per-lamp brightness from `0` through `255` and choose `solid`, `blink`, or `pulse`.
- Use Ctrl+Shift+D to open the assignment list, jump to a lamp, edit brightness/effect values, or remove an assignment.
- Enable Factorio Alt mode to show the green channel-number marker on assigned lamps.

The in-game channel number is one-based: lamp channel `1` becomes wire channel `0`, and lamp channel `64` becomes wire channel `63`. Assigning an occupied channel transfers it to the newly selected lamp. Assignments, brightness/effect settings, the per-save ID, and packet sequence are stored in the save.

The mod reads the lamp control behavior's evaluated color every tick. Circuit enable/disable, signal color mapping, separate RGB signals, and packed RGB therefore remain configured through Factorio's normal lamp interface. A disabled, unpowered, low-power, or daytime-off lamp is sent as black.

The mod's startup settings select the UDP destination port and the default brightness for new assignments. Default brightness is `64`; the startup setting accepts `16..255`, while an individual assignment can subsequently be set to `0..255`.

### 3. Flash and provision a controller

Build and flash the firmware over USB:

```sh
cd firmware
pio run -e esp32-c3-supermini -t upload
pio device monitor
```

The image targets an ESP32-C3 DevKitM-compatible SuperMini, uses GPIO4 for NeoPixel data and GPIO9 for BOOT, and identifies itself as firmware `2.0.0`.

On first boot, join the `Factorio-Display-xxxxxx` access point and configure:

- Wi-Fi credentials.
- The Mosquitto host's LAN address and port `1883`.
- MQTT username `device` and the password in `secrets/device_password`.
- A unique device ID using at most 32 letters, digits, dots, underscores, or hyphens.
- Pixel count `1..16`, channel offset `0..63`, and `RGB` or `GRB` pixel order.

The range must satisfy `channel_offset + pixel_count <= 64`. Pixel zero displays the offset channel; each later pixel displays the next channel. For example, two eight-pixel controllers use `(pixel_count=8, offset=0)` and `(pixel_count=8, offset=8)`.

Wi-FiManager stores Wi-Fi data in the ESP Wi-Fi configuration, while MQTT and display settings are stored in the firmware's NVS namespace. If Wi-Fi cannot connect, the captive portal starts automatically and remains available for up to five minutes. Holding BOOT continuously for five seconds requests the portal explicitly.

During normal operation, the same MQTT/display settings are available at either:

```text
http://<controller-ip>/
http://factorio-display-<device-id>.local/
```

The normal page does not display the saved MQTT password; leave the password field empty to keep it. Saving restarts the controller, and the confirmation page attempts to return to `/` after ten seconds. This page uses plain HTTP and belongs only on the trusted LAN. Firmware updates are USB-only.

If a logical green value lights red, change the pixel order between `RGB` and `GRB` on the controller page.

## Runtime behavior

The mod evaluates assigned lamps every game tick. It sends an `update` as soon as a value changes, a complete `snapshot` every 300 ticks (five seconds at 60 UPS), and a complete `reset` when a saved game is loaded. Removed assignments generate one black update for their former channel.

The daemon validates protocol version 2, packet shape, channel range, direct colors/effects, and sequence ordering. A `reset` is authoritative: it may establish a lower sequence after reloading an older save, replaces all channel state, and becomes the new sequence baseline. Snapshots also replace all state; updates merge only their listed channels.

The daemon publishes immediately after each accepted UDP packet and configuration reload, and republishes every five seconds. Each retained frame contains exactly 64 channels and expires on the controller after seven seconds. Unassigned channels are black with brightness `255` and `solid` effect.

If no valid full snapshot or reset arrives for more than ten seconds, every channel uses the configurable `stale_game` color (cyan pulse by default). An ESP with MQTT connected but no valid unexpired frame displays black. An ESP disconnected from MQTT displays an amber breathing pattern. These are three separate states.

Although the current mod sends direct RGB lamp records, the daemon still accepts legacy/status records and requires all status colors in YAML. Defaults are green working, yellow pulse starved, red blocked, blue blink no power, purple disabled, magenta missing, white unknown, and cyan pulse stale game. Direct lamp records carry their own `0..255` brightness and effect.

Each controller publishes retained `online`/`offline` availability, using an MQTT Last Will for unclean disconnects. Every 30 seconds it publishes non-retained telemetry with firmware version, IP address, RSSI, uptime, pixel count, channel offset, and pixel order.

## Development and verification

```sh
make test                    # Go, isolated Lua, and native firmware tests
make build-firmware          # compile the ESP32-C3 firmware
make compose-config          # validate the Compose model
./scripts/integration-test.sh
```

The integration test requires generated credentials and Docker. It uses UDP port `44198` by default, verifies status conversion and direct-lamp pass-through, exercises valid and invalid YAML reloads, observes the retained MQTT frame, and waits for the stale-game transition. Override its UDP port with `DISPLAY_INTEGRATION_UDP_PORT`.

Detailed wire formats and topics are in [the protocol reference](docs/protocol.md). The manual Factorio acceptance checklist lives under `factorio-mod/tests`.

## Troubleshooting

- **Daemon logs `invalid udp packet`:** confirm the sender uses protocol version 2, a positive sequence, a `channels` array (or `{}` only when empty), and channel IDs `0..63`.
- **Daemon logs `out-of-order packet ignored` after loading an older save:** the first authoritative packet must be type `reset`; subsequent packets must use larger sequences.
- **Controller cannot authenticate to MQTT:** open its normal HTTP page and replace the MQTT password. The daemon uses different credentials from devices.
- **Controller is amber:** MQTT is disconnected. Check broker address, LAN reachability, username/password, and Mosquitto port `1883`.
- **Controller is black:** MQTT is connected but no complete, valid, unexpired global frame has been accepted.
- **All pixels show cyan pulse:** MQTT is working, but the daemon has not received a full Factorio snapshot/reset for more than ten seconds.
- **Colors are swapped:** select the matching `RGB` or `GRB` order in controller configuration.

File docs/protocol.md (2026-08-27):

# Version 2 protocol reference

There are exactly 64 logical channels. The Factorio interface displays them as `1..64`; UDP and MQTT use `0..63`.

## Factorio to daemon: UDP

The daemon listens on UDP port `34198`, published by Compose only on host loopback. A packet has this envelope:

```json
{
  "version": 2,
  "save_id": "12345678-90abcdef",
  "sequence": 42,
  "tick": 1234,
  "type": "snapshot",
  "channels": [
    {"id": 0, "r": 0, "g": 255, "b": 0, "brightness": 192, "effect": "solid"}
  ]
}
```

Envelope rules:

- `version` must be `2`, `save_id` must be non-empty, and `sequence` must be positive.
- `type` is `snapshot`, `update`, or `reset`.
- Channel IDs must be unique integers in `0..63`.
- Unknown JSON fields and trailing JSON data are rejected.
- Factorio serializes an empty Lua table as `{}`. The daemon accepts `"channels": {}` only as an empty list; a non-empty channel object is invalid.

Packet behavior:

- `snapshot` replaces the complete state, establishes the last full-snapshot time, and is normally sent every 300 game ticks.
- `update` merges only the listed channels. It does not refresh the full-snapshot heartbeat.
- `reset` is an authoritative snapshot used when a save is loaded. It bypasses the prior ordering check, replaces the active save ID and all channels, refreshes the heartbeat, and resets sequence tracking to its own sequence.
- Non-reset packets with a sequence less than or equal to the last accepted sequence for their save ID are ignored.

The current lamp mod sends direct-color channel records. All five color fields are required together, and a direct record may not also contain `status`:

```json
{"id": 8, "r": 255, "g": 80, "b": 0, "brightness": 192, "effect": "pulse"}
```

RGB and brightness values are integers in `0..255`. Effect is `solid`, `blink`, or `pulse`.

The daemon also accepts status records for compatibility and testing:

```json
{"id": 0, "status": "working"}
```

Raw statuses are classified as follows:

| Output | Accepted raw values |
|---|---|
| `working` | `working`, `normal` |
| `starved` | `no-ingredients`, `item-ingredient-shortage`, `fluid-ingredient-shortage`, `no-fuel`, `no-recipe` |
| `blocked` | `full-output`, `full-burnt-result-output`, `waiting-for-space-in-destination` |
| `no_power` | `no-power`, `low-power`, `not-plugged-in-electric-network` |
| `disabled` | `disabled`, `disabled-by-control-behavior`, `disabled-by-script`, `closed-by-circuit-network`, `marked-for-deconstruction`, `recipe-not-researched` |
| `missing` | `missing` |
| `unknown` | every other non-empty status |

## Daemon to controllers: MQTT

The daemon publishes retained QoS 1 frames to:

```text
factorio-display/v2/channels/set
```

A frame always contains exactly one unique record for every channel `0..63`:

```json
{
  "version": 2,
  "sequence": 9,
  "expires_in_ms": 7000,
  "channels": [
    {"channel": 0, "r": 0, "g": 255, "b": 0, "brightness": 192, "effect": "solid"}
  ]
}
```

The example array is abbreviated. MQTT frame sequences are generated by the daemon and increase on every publication; they are independent from Factorio packet sequences. The daemon publishes on startup, after every accepted UDP packet, after a valid color reload, on a stale/fresh transition, and every five seconds.

`expires_in_ms` is a relative lifetime so an ESP does not require a wall clock. Controllers accept `1..60000` milliseconds; daemon frames use `7000`. Omitted brightness defaults to `255` for compatibility, but daemon-generated frames always include it.

The controller validates the complete global frame before changing any pixels. It rejects malformed JSON, a wrong version, incomplete or duplicate channels, invalid values/effects, an invalid expiry, or a non-increasing sequence. After MQTT reconnect it resets its local sequence baseline so the broker's retained frame—or a restarted daemon—can restore the display.

Each controller stores `pixel_count` and `channel_offset`. Local pixel `n` uses global channel `channel_offset + n`, with these constraints:

```text
1 <= pixel_count <= 16
0 <= channel_offset <= 63
channel_offset + pixel_count <= 64
```

## Device topics

For a configured device ID, firmware uses:

```text
factorio-display/v2/device/<device-id>/availability
factorio-display/v2/device/<device-id>/telemetry
```

Availability is a retained plain-text `online` or `offline` value. The MQTT Last Will publishes retained `offline` at QoS 1 after an unclean disconnect. The firmware explicitly publishes retained `online` after connecting.

Telemetry is non-retained JSON published every 30 seconds:

```json
{
  "version": 1,
  "firmware": "2.0.0",
  "ip": "192.168.1.50",
  "rssi": -55,
  "uptime_s": 1234,
  "pixel_count": 8,
  "channel_offset": 0,
  "pixel_order": "RGB"
}
```

Mosquitto ACLs allow the `daemon` user to publish global frames and inspect device availability/telemetry. The `device` user can read global frames and publish only device availability/telemetry topics.

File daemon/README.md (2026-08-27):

# Factorio display daemon

The daemon receives Factorio display protocol version 2 packets over UDP, maintains the current state of 64 logical channels, and publishes complete retained frames to MQTT for the ESP32-C3 controllers.

It accepts direct RGB lamp values as well as status values, rejects malformed and out-of-order packets, and switches the complete frame to the configured `stale_game` color when no full snapshot or reset has arrived for more than ten seconds.

See [the protocol reference](../docs/protocol.md) for packet schemas, sequence behavior, and MQTT topics.

## Dependencies

For a native build:

- Go 1.24 or newer, as declared by `go.mod`.
- An MQTT 3.1.1 broker reachable from the daemon.
- A version 2 UDP sender, normally the `lamp_led_display` Factorio mod.
- A valid YAML configuration file.

Direct Go dependencies are:

- `github.com/eclipse/paho.mqtt.golang` for MQTT.
- `gopkg.in/yaml.v3` for strict YAML parsing.

The daemon does not require CGo. The Docker build uses `golang:1.26-alpine`, produces a static binary, and copies it into an `alpine:3.24` runtime image. No runtime packages are installed, and the process runs as numeric UID/GID `65532` rather than root.

## Build and test

From the repository root:

```sh
cd daemon
go test ./...
go build -o factorio-display ./cmd/factorio-display
```

The repository Makefile also provides:

```sh
make test-go
```

Build the container from the repository root:

```sh
docker build -t factorio-display-daemon ./daemon
```

The equivalent optimized static build used by the Dockerfile is:

```sh
cd daemon
CGO_ENABLED=0 go build -trimpath -ldflags="-s -w" -o factorio-display ./cmd/factorio-display
```

## Configuration file

Start from the repository example:

```sh
cp config.example.yaml config.yaml
```

The schema is:

```yaml
mqtt:
  broker: tcp://localhost:1883
  client_id: factorio-display-daemon
  prefix: factorio-display/v2

colors:
  working:    {r: 0,   g: 255, b: 0,   effect: solid}
  starved:    {r: 255, g: 180, b: 0,   effect: pulse}
  blocked:    {r: 255, g: 0,   b: 0,   effect: solid}
  no_power:   {r: 0,   g: 80,  b: 255, effect: blink}
  disabled:   {r: 150, g: 0,   b: 255, effect: solid}
  missing:    {r: 255, g: 0,   b: 180, effect: solid}
  unknown:    {r: 255, g: 255, b: 255, effect: solid}
  stale_game: {r: 0,   g: 255, b: 255, effect: pulse}
```

Configuration rules:

- `mqtt.broker` is required. Paho accepts broker URLs such as `tcp://localhost:1883`.
- `mqtt.client_id` defaults to `factorio-display-daemon` when omitted.
- `mqtt.prefix` defaults to, and must equal, `factorio-display/v2`. A trailing slash is removed before validation.
- Every listed color is required, even if the current Factorio mod sends only direct RGB lamp records.
- RGB components are YAML integers in `0..255`.
- Effects must be `solid`, `blink`, or `pulse`.
- Unknown YAML fields are rejected.

The daemon checks the file modification time once per second. A fully valid edit is applied without restart and immediately publishes a new frame. Invalid changes are logged and the previous valid configuration remains active. MQTT broker and client-ID changes are rejected during reload and require a restart. The protocol prefix is fixed and cannot be changed.

## Command-line interface

```text
factorio-display [-config PATH] [-udp ADDRESS]
```

| Flag | Environment fallback | Default | Description |
| --- | --- | --- | --- |
| `-config PATH` | `DISPLAY_CONFIG` | `/config/display.yaml` | YAML configuration file |
| `-udp ADDRESS` | `DISPLAY_UDP_ADDR` | `:34198` | Address passed to Go's UDP listener |

An explicitly supplied flag overrides its environment fallback. Useful UDP values include:

- `:34198` to listen on all interfaces.
- `127.0.0.1:34198` to listen only on host loopback.
- `:44198` to use a different port for testing.

## Environment variables

| Variable | Required | Purpose |
| --- | --- | --- |
| `DISPLAY_CONFIG` | No | Default for `-config` |
| `DISPLAY_UDP_ADDR` | No | Default for `-udp` |
| `MQTT_USERNAME_FILE` | One username source | Read the MQTT username from a file |
| `MQTT_USERNAME` | One username source | Supply the MQTT username directly |
| `MQTT_PASSWORD_FILE` | One password source | Read the MQTT password from a file |
| `MQTT_PASSWORD` | One password source | Supply the MQTT password directly |
| `LOG_LEVEL` | No | Set to `debug` for debug logging; every other value uses `info` |

For each credential, the corresponding `*_FILE` variable takes precedence over the direct value. Leading and trailing whitespace is removed from file contents. File-based credentials are recommended because direct environment values may be exposed by process or container inspection.

## Run the native binary

Using direct credential variables:

```sh
cd daemon
MQTT_USERNAME=daemon \
MQTT_PASSWORD='replace-me' \
./factorio-display \
  -config ../config.yaml \
  -udp 127.0.0.1:34198
```

Using credential files:

```sh
cd daemon
MQTT_USERNAME_FILE=../secrets/daemon_username \
MQTT_PASSWORD_FILE=../secrets/daemon_password \
LOG_LEVEL=debug \
./factorio-display \
  -config ../config.yaml \
  -udp 127.0.0.1:34198
```

For a native process, set `mqtt.broker` to a broker address reachable from the host, commonly `tcp://localhost:1883`. The example configuration uses `tcp://mosquitto:1883`, which is the Compose service name and normally resolves only inside the Compose network.

The process writes structured JSON logs to standard output. `SIGINT` and `SIGTERM` trigger a graceful shutdown, including MQTT disconnect and UDP listener cleanup.

## Run with Docker Compose

From the repository root:

```sh
cp config.example.yaml config.yaml
./scripts/create-credentials.sh
docker compose up -d --build
docker compose logs -f daemon
```

The supplied Compose model:

- Builds the daemon from `daemon/Dockerfile`.
- Mounts `config.yaml` read-only at `/config/display.yaml`.
- supplies the daemon username/password through Compose secrets.
- publishes container UDP port `34198` as `127.0.0.1:34198/udp` on the host.
- connects to Mosquitto at `tcp://mosquitto:1883`.
- publishes Mosquitto TCP port `1883` to the LAN for controllers.

Stop the stack with:

```sh
docker compose down
```

## Runtime behavior

On startup the daemon validates configuration and credentials, connects to MQTT, opens the UDP socket, and publishes an initial stale frame. It then:

- Publishes immediately after every accepted UDP packet.
- Republishes the retained complete frame every five seconds.
- Publishes immediately after a valid color reload or stale/fresh transition.
- Uses a seven-second relative frame expiry.
- Treats Factorio as stale after ten seconds without a valid `snapshot` or `reset`; an `update` alone does not refresh this heartbeat.
- Accepts an authoritative `reset` even when its Factorio sequence is lower, then uses that reset sequence as the new baseline.
- Publishes retained QoS 1 frames to `factorio-display/v2/channels/set`.

Malformed UDP packets and out-of-order non-reset packets are logged and ignored. MQTT publishing errors are logged without terminating the main loop. Startup failures, including an unreadable configuration, missing credentials, MQTT connection failure, or inability to bind UDP, terminate the process with a nonzero exit status.

## Security and networking

Factorio's Lua UDP API is localhost-only, so a host-native daemon should bind to `127.0.0.1:34198`. Compose safely achieves the same host exposure even though the daemon listens on `:34198` inside its container.

The included Mosquitto setup uses username/password authentication without TLS. It is intended for a trusted LAN. The `daemon` user can publish global frames and read device availability/telemetry; the `device` user can read global frames and publish device availability/telemetry.

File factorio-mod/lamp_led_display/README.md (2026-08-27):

# Lamp LED Display

Move Factorio Lamps into the real world. This mod is probably not useful to you, unless you also spend time to setup the supporting infrastructure. And maybe build a bit of hardware.

Allows selecting Lamps in the game and assigning LED channels to them. This information is then sent out through the Factorio UDP interface to a process listening to it.

To use this mod, you *MUST* run Factorio with the `--enable-lua-udp <port number>` option. I use 34199 for the game. UDP packets are, by default, sent to port 34198. This can be changed in the mod settings.

## Credits

Graphics:

* [Bulb icons created by AB Design - Flaticon](https://www.flaticon.com/free-icons/bulb)
* [Order icons created by Magnific - Flaticon](https://www.flaticon.com/free-icons/order)

## Legal & Copyright

The code was partially written and reviewed by AI coding agents. If you are fundamentally opposed to using AI tools to develop software and improve software quality, you are free to not install it.

--------------------------------------------------
Copyright (C) 2026 Henning Schmiedehausen (@hgschmie), licensed under the MIT license.

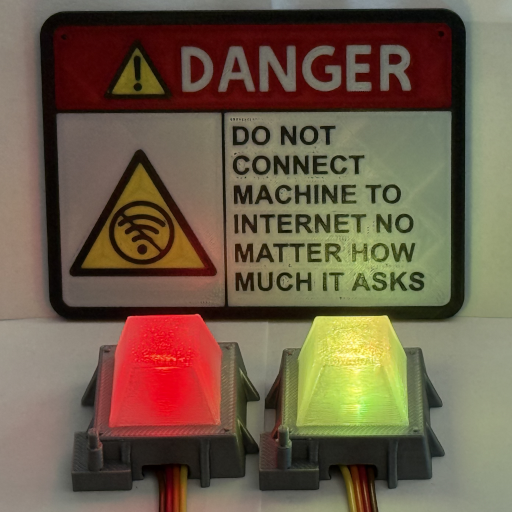
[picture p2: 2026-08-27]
factorio-mod/lamp_led_display/graphics/images/thumbnail.png

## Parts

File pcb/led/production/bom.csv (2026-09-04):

Designator | Footprint | Quantity | Value | LCSC Part #
D1 | LED_D5.0mm-4_RGB | 1 | WS2812B_5mm_Through_hole
J1, J2 | PinHeader_1x02_P2.54mm_Horizontal | 2 | Conn_01x02_Pin

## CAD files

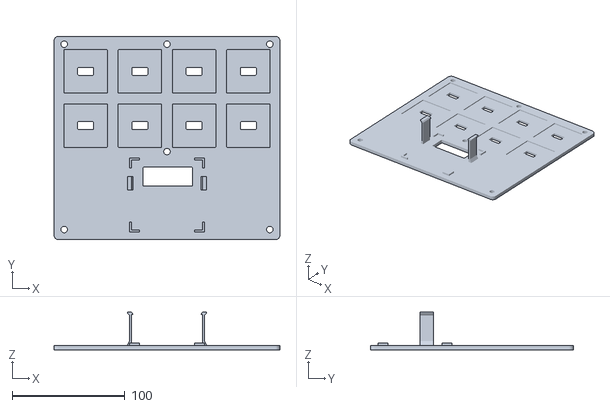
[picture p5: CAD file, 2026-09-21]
3dprint/baseplate/reference/centered-slot/lamp-base-plate.stl
200.0 x 180.0 x 33.3

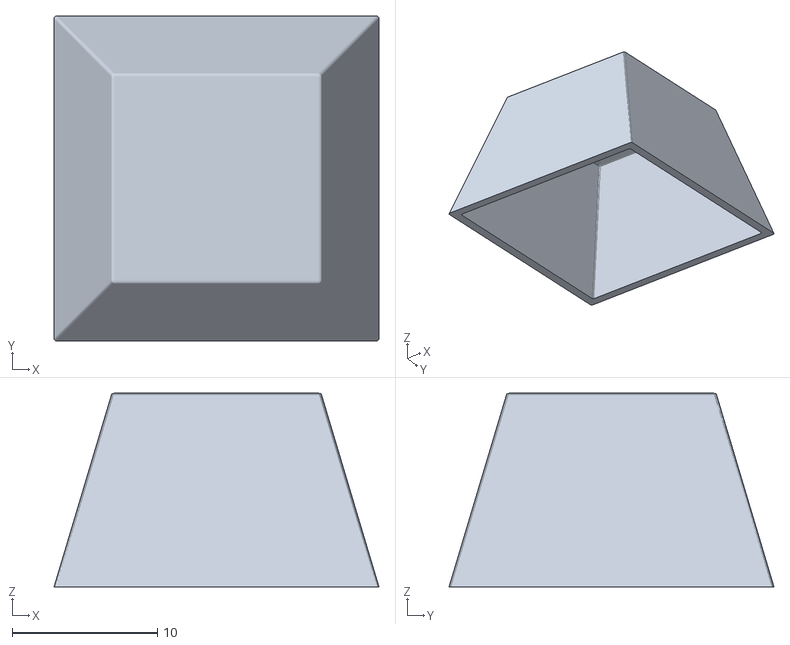
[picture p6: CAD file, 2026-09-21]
3dprint/baseplate/reference/lamp-dome.stl
22.4 x 22.4 x 13.4

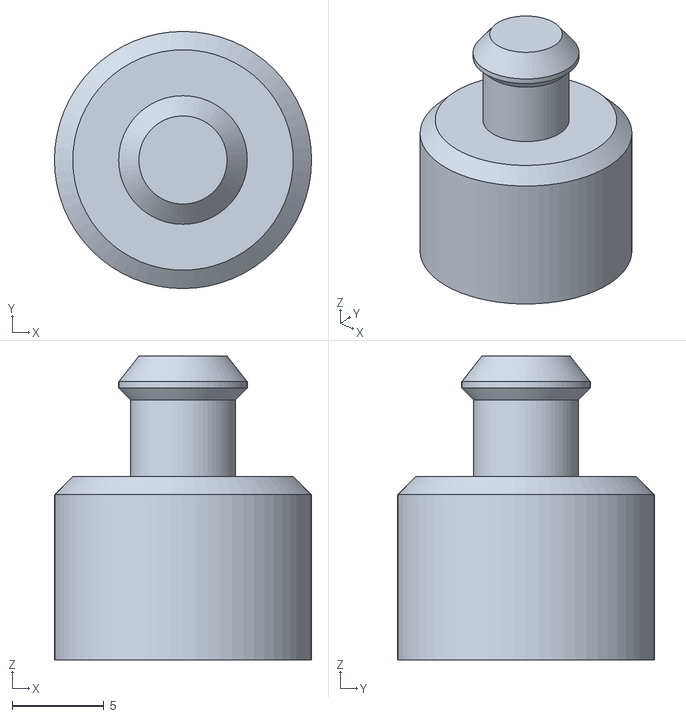
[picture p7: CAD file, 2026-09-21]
3dprint/baseplate/reference/tpu-v1/foot-tpu95a.stl
14.0 x 14.0 x 16.5

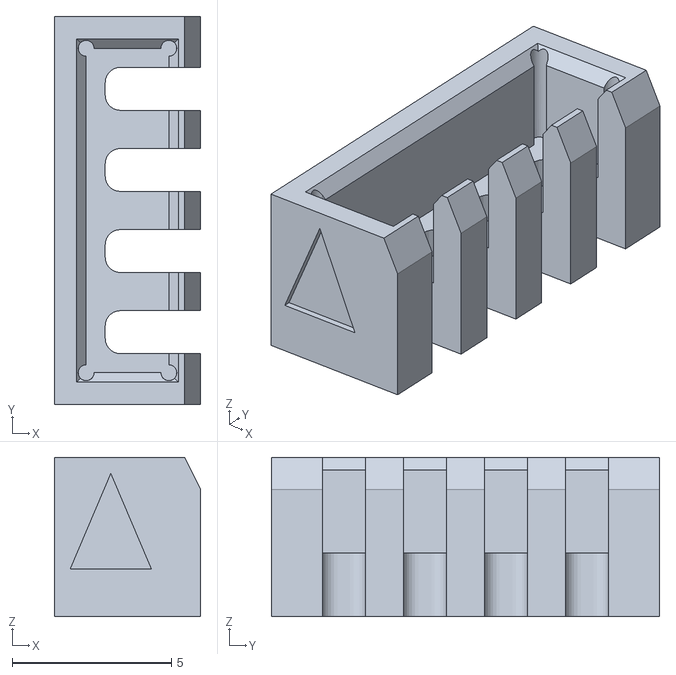
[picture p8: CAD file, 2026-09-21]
3dprint/connector/wire-connector.stl
4.60 x 12.2 x 5.00

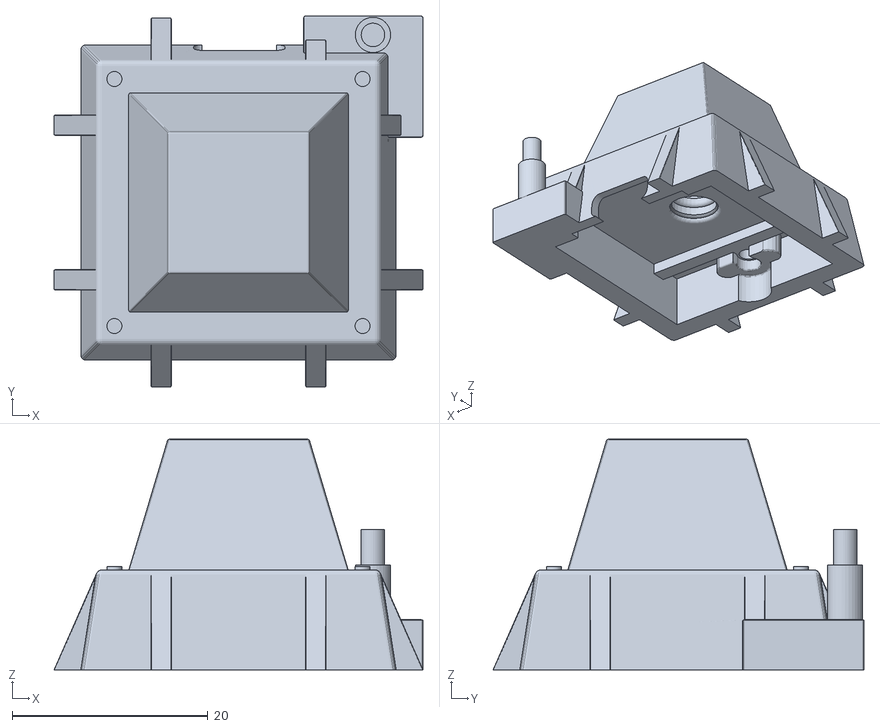
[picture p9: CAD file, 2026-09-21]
3dprint/lamp/lamp.stl
37.7 x 37.9 x 23.6

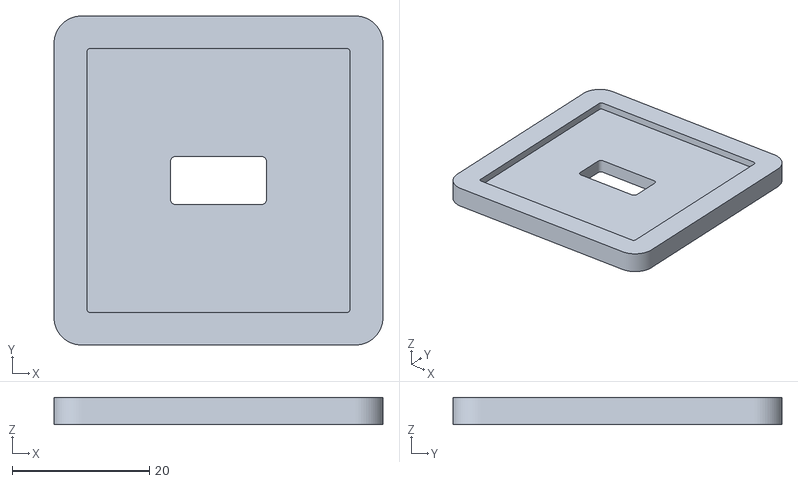
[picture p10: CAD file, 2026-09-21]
3dprint/baseplate/reference/centered-slot/lamp-fit-test.stl
48.0 x 48.0 x 4.00

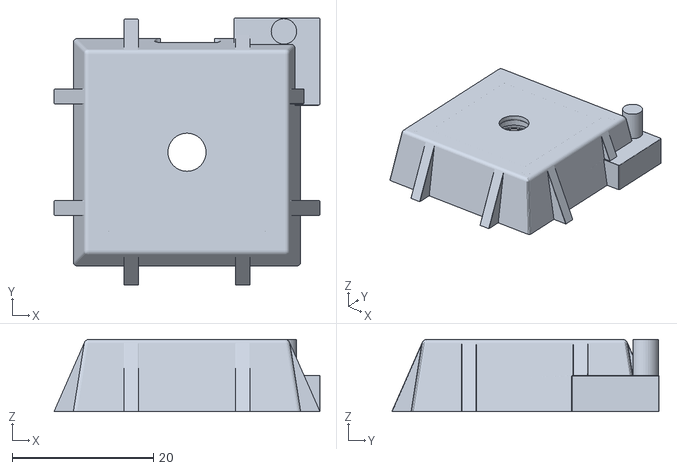
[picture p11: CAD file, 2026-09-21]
3dprint/baseplate/reference/lamp-base.stl
37.7 x 37.9 x 10.2

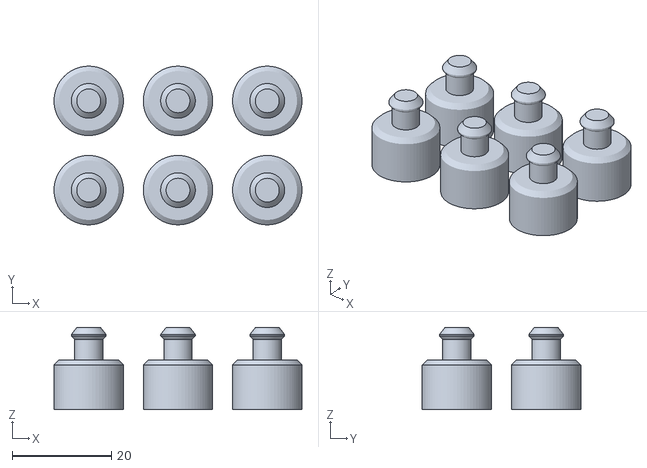
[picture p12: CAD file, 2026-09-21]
3dprint/baseplate/reference/tpu-v1/feet-tpu95a.stl
50.0 x 32.0 x 16.5

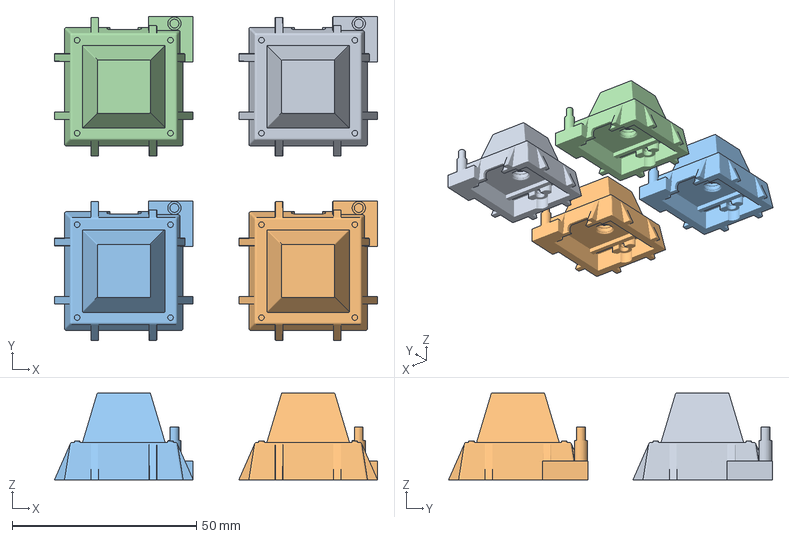
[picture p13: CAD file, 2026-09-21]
3dprint/lamp/Factorio Lamp - PLA.3mf
87.7 x 87.9 x 23.6 mm
Factorio Lamp x 4

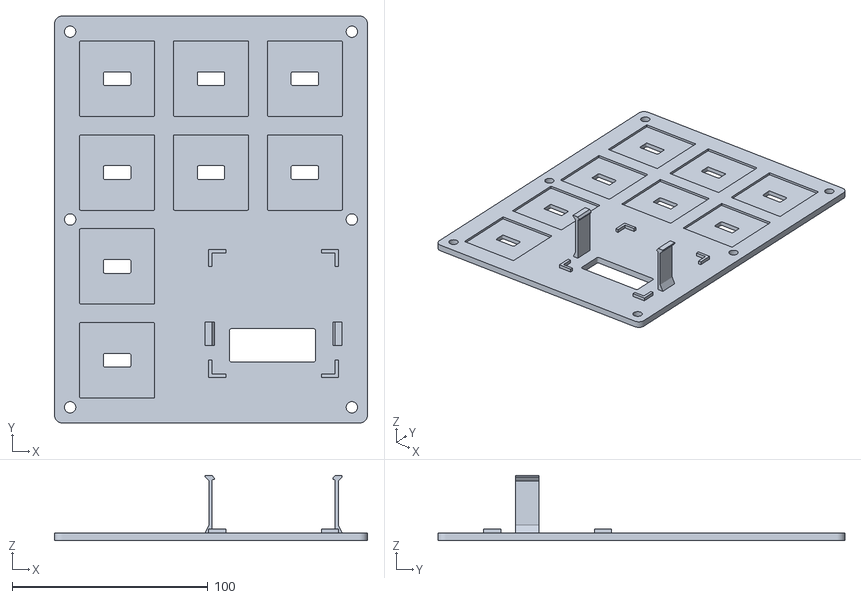
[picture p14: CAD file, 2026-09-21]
3dprint/baseplate/reference/centered-slot/lamp-base-plate-alternative.stl
160.0 x 208.0 x 33.3

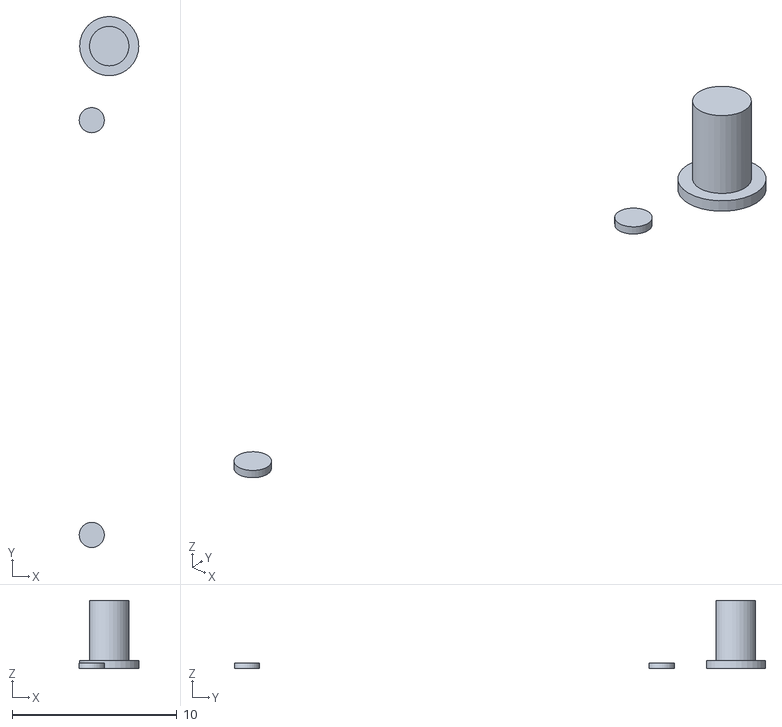
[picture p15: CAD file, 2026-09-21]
3dprint/baseplate/reference/lamp-antenna.stl
3.63 x 32.3 x 4.15

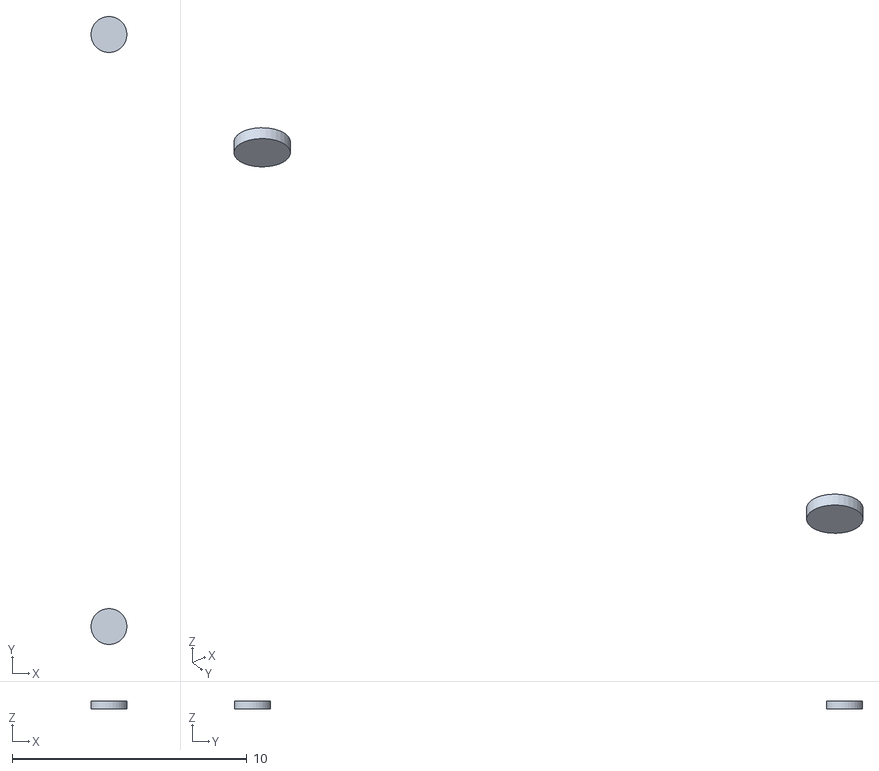
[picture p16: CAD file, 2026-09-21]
3dprint/baseplate/reference/lamp-screws.stl
1.53 x 26.7 x 0.342

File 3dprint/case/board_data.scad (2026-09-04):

// GENERATED by kicad2scad.py from pcb.kicad_pcb -- do not edit by hand.
// Board-local coordinates: origin lower-left, y up, millimetres.

pcb_size = [55, 55];
pcb_thickness = 1.6;

// [ref, x, y, drill]
pcb_holes = [
  ["H1", 4, 51, 3.2],
  ["H2", 51, 51, 3.2],
  ["H3", 4, 4, 3.2],
  ["H4", 51, 4, 3.2],
];

// [ref, x0, y0, x1, y1] -- pad-centre extents of the 1x4 LED headers
pcb_headers = [
  ["J1", 10, 7.38, 10, 15],
  ["J2", 15, 7.38, 15, 15],
  ["J3", 20, 7.38, 20, 15],
  ["J4", 25, 7.38, 25, 15],
  ["J5", 30, 7.38, 30, 15],
  ["J6", 35, 7.38, 35, 15],
  ["J7", 40, 7.38, 40, 15],
  ["J8", 45, 7.38, 45, 15],
];

// [ref, value, x0, y0, x1, y1] -- courtyard extents of components
pcb_parts = [
  ["C1", "1000uF", 12.75, 42.25, 23.25, 52.75],
  ["C2", "100nF", 28.45, 43.5, 35.55, 46.5],
  ["H1", "M3", 0.55, 47.55, 7.45, 54.45],
  ["H2", "M3", 47.55, 47.55, 54.45, 54.45],
  ["H3", "M3", 0.55, 0.55, 7.45, 7.45],
  ["H4", "M3", 47.55, 0.55, 54.45, 7.45],
  ["J1", "LED 1 5V/GND/DIN/DOUT", 8.23, 5.61, 11.77, 16.77],
  ["J2", "LED 2 5V/GND/DIN/DOUT", 13.23, 5.61, 16.77, 16.77],
  ["J3", "LED 3 5V/GND/DIN/DOUT", 18.23, 5.61, 21.77, 16.77],
  ["J4", "LED 4 5V/GND/DIN/DOUT", 23.23, 5.61, 26.77, 16.77],
  ["J5", "LED 5 5V/GND/DIN/DOUT", 28.23, 5.61, 31.77, 16.77],
  ["J6", "LED 6 5V/GND/DIN/DOUT", 33.23, 5.61, 36.77, 16.77],
  ["J7", "LED 7 5V/GND/DIN/DOUT", 38.23, 5.61, 41.77, 16.77],
  ["J8", "LED 8 5V/GND/DIN/DOUT", 43.23, 5.61, 46.77, 16.77],
  ["R1", "390R", 8.95, 18.8, 21.21, 21.8],
  ["TP1", "+5V TEST", 8.7, 48.2, 12.3, 51.8],
  ["TP2", "GND TEST", 8.7, 42.7, 12.3, 46.3],
  ["TP3", "GPIO4 TEST", 23.7, 45.7, 27.3, 49.3],
  ["TP4", "DATA5V TEST", 2.2, 13.2, 5.8, 16.8],
  ["TP5", "LED8 DOUT", 43.2, 21.7, 46.8, 25.3],
  ["U1", "ESP32-C3-SUPER-MINI", 0.77, 22.73, 21.85, 41.27],
  ["U2", "74AHCT125", 25.36, 22.795, 36.02, 41.205],
];

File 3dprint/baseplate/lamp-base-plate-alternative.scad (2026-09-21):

// Portrait alternative: 3 + 3 lamps above, 2 down the left beside the box.
// Reuses the original recess, clips, connector slots and TPU foot geometry.
use <lamp-base-plate.scad>
part = "plate"; // [plate,assembly]
alt_width = 160;
alt_depth = 208;
alt_lamps = [[32,176],[80,176],[128,176],
             [32,128],[80,128],[128,128],[32,80],[32,32]];
alt_feet = [[8,8],[152,8],[8,200],[152,200],[8,104],[152,104]];
alt_box = [80.9,25.5];
$fn = 64;

// Move the complete original box mount as a unit, rotating it 180 degrees
// in plan so its side connector port faces the outer right edge.
module box_placement() {
    translate([alt_box[0]+62.2+68.9,alt_box[1]+61+9,0])
        rotate([0,0,180]) children();
}
module alternative_plate() {
    union() {
        difference() {
            deck(alt_width,alt_depth);
            for(p=alt_lamps) translate([p[0],p[1],0]) lamp_cut();
            box_placement() box_cut();
            for(p=alt_feet) translate([p[0],p[1],-0.02]) cylinder(d=5.8,h=4.04);
        }
        box_placement() box_mount();
        for(p=alt_lamps) translate([p[0],p[1],0])
            lamp_lips(box_direction(p,[alt_box[0]+62.2/2,alt_box[1]+61/2]));
    }
}
module alternative_lamps() {
    for(p=alt_lamps) translate([p[0],p[1],2.6]) reference_lamp();
}
module alternative_box() {
    translate([alt_box[0]+62.2,alt_box[1],31.02426407]) rotate([0,180,0]) {
        color([0.56,0.59,0.61]) import("../case/out/base.stl");
        color([0.4,0.44,0.46]) import("../case/out/lid.stl");
    }
}
module alternative_feet() {
    for(p=alt_feet) translate([p[0],p[1],-10]) tpu_foot();
}
module alternative_assembly() {
    color([0.28,0.39,0.46]) alternative_plate();
    alternative_lamps();
    alternative_box();
    color([0.18,0.21,0.23]) alternative_feet();
}

if(part=="plate") alternative_plate();
else if(part=="assembly") alternative_assembly();
else assert(false,"Unknown part");

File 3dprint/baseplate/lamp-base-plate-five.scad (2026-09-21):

// Five-lamp plate: 3 lamps above, 2 down the left beside the box.
// Reuses the original recess, clips, connector slots and TPU foot geometry.
use <lamp-base-plate.scad>
part = "plate"; // [plate,assembly]
five_width = 160;
five_depth = 160;
five_lamps = [[32,128],[80,128],[128,128],[32,80],[32,32]];
five_feet = [[8,8],[152,8],[8,152],[152,152],[8,80],[152,80]];
five_box = [80.9,25.5];
$fn = 64;

// Move the complete original box mount as a unit, rotating it 180 degrees
// in plan so its side connector port faces the outer right edge.
module box_placement() {
    translate([five_box[0]+62.2+68.9,five_box[1]+61+9,0])
        rotate([0,0,180]) children();
}
module five_plate() {
    union() {
        difference() {
            deck(five_width,five_depth);
            for(p=five_lamps) translate([p[0],p[1],0]) lamp_cut();
            box_placement() box_cut();
            for(p=five_feet) translate([p[0],p[1],-0.02]) cylinder(d=5.8,h=4.04);
        }
        box_placement() box_mount();
        for(p=five_lamps) translate([p[0],p[1],0])
            lamp_lips(box_direction(p,[five_box[0]+62.2/2,five_box[1]+61/2]));
    }
}
module five_lamps() {
    for(p=five_lamps) translate([p[0],p[1],2.6]) reference_lamp();
}
module five_box() {
    translate([five_box[0]+62.2,five_box[1],31.02426407]) rotate([0,180,0]) {
        color([0.56,0.59,0.61]) import("../case/out/base.stl");
        color([0.4,0.44,0.46]) import("../case/out/lid.stl");
    }
}
module five_feet() {
    for(p=five_feet) translate([p[0],p[1],-10]) tpu_foot();
}
module five_assembly() {
    color([0.28,0.39,0.46]) five_plate();
    five_lamps();
    five_box();
    color([0.18,0.21,0.23]) five_feet();
}

if(part=="plate") five_plate();
else if(part=="assembly") five_assembly();
else assert(false,"Unknown part");

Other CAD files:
3dprint/lamp/Factorio Lamp - PETG.3mf
3dprint/baseplate/lamp-base-plate.scad
3dprint/baseplate/lamp-position-cover.scad
3dprint/baseplate/reference/check-alternative-clearance.scad
3dprint/baseplate/reference/check-clearance.scad
3dprint/baseplate/reference/check-five-clearance.scad
3dprint/baseplate/reference/inspect.scad
3dprint/baseplate/reference/lamp-lip-proposal.scad
3dprint/baseplate/reference/lamp-slot-comparison.scad
3dprint/case/case.scad

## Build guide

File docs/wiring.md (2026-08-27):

# Controller and NeoPixel wiring

The personal-use PCB carries an ESP32-C3 SuperMini, a 74AHCT125 level shifter, bulk capacitance, and eight four-pin LED connectors. It is powered through the ESP module's USB-C connector; the module's 5 V/VBUS output supplies the level shifter and LEDs.

```text
USB-C / ESP32-C3 SuperMini       74AHCT125                  first NeoPixel

GPIO4 (3.3 V) ────────────────► 1A
GND ──────────────────────────► /1OE and GND
5 V/VBUS ─────────────────────► VCC ─────────────────────► VCC
                                1Y ── 330–470 Ω ─────────► DIN
GND ─────────────────────────────────────────────────────► GND

C1: approximately 1000 µF between 5 V/VBUS and GND
```

The 74AHCT125 accepts the ESP's 3.3 V GPIO signal and produces a 5 V data signal. Its active-low output enable is tied low. All unused level-shifter inputs are tied to ground rather than left floating. All ESP, level-shifter, and LED grounds must be common.

Observe the bulk capacitor's polarity, place the 330–470 Ω resistor in series with the level-shifted data output, and keep the controller-to-first-pixel data lead short.

## LED connector pinout

Each of the eight 1x4 male connectors follows the LED's physical pin order so four straight conductors can be used:

1. Data In
2. +5 V (Vcc)
3. GND
4. Data Out

The chain runs from the level-shifter output into connector 1 Data In, then from each LED's Data Out to the next connector's Data In. The board distributes common +5 V and ground to every connector.

## Firmware relationship

The firmware drives an 800 kHz NeoPixel stream on GPIO4. Pixel order is configurable as `RGB` or `GRB`; select the order expected by the installed LEDs. If a requested green pixel appears red, switch the configured order.

Firmware supports `1..16` pixels, but this PCB exposes eight connectors. Device pixel count should normally therefore be configured as `8` or fewer for this board.

Holding the ESP32-C3 SuperMini BOOT button pulls GPIO9 low. The firmware detects a continuous five-second hold and restarts into captive provisioning; GPIO9 is not part of the LED wiring.

## Power budget

For eight LEDs specified at 12 mA maximum each, the maximum LED load is 96 mA at full brightness. The firmware permits the full `0..255` brightness range. Allow additional current for the ESP32-C3 and level shifter, and use a sound USB-C supply and cable.

This design intentionally uses the ESP module's 5 V/VBUS rail and has no separate LED power connector. Do not apply a second independent 5 V source at the same time. C1 remains fitted to support transient LED current.

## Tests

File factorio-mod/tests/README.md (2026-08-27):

# In-game acceptance checklist

1. Launch Factorio 2.1 with `--enable-lua-udp 34199` and enable the mod. Port 34199 is Factorio's local port; the daemon receives the mod's packets on port 34198.
2. Place two standard lamps. Use the shortcut or Alt+Shift+D, drag over exactly one lamp, and assign it channel `1` with the numeric field. Assign the other lamp channel `64`.
3. Enable Alt mode and verify each assigned lamp shows its channel marker; disable Alt mode and confirm the markers are hidden.
4. Assign an already-used channel to the other lamp and confirm ownership moves to that lamp. Close an unassigned lamp's dialog and confirm no assignment is created.
5. In the assignment dialog, test brightness values `0` and `255` and select each of `solid`, `blink`, and `pulse`.
6. Open the assignment list with Ctrl+Shift+D. Confirm both channels are sorted numerically, edit brightness and effect values there, use the camera to jump to a lamp, and remove an assignment.
7. Connect a lamp to the circuit network. Verify enabled and disabled states, fractional and byte RGB values, color mapping, separate RGB signals, and packed RGB mode reach the corresponding physical LED.
8. Observe changed lamp state arriving in an `update` within one tick and complete `snapshot` packets every 300 ticks (five seconds at 60 UPS). Confirm channel `1` is sent as UDP channel `0` and channel `64` as UDP channel `63`.
9. Save and reload. Confirm the save ID, sequence, assignments, brightness/effects, and Alt-mode markers persist, and that loading emits a complete `reset` packet before normal updates resume.

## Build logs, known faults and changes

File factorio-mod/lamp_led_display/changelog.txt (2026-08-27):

---------------------------------------------------------------------------------------------------
Version: 1.0.1
Date: ????
  Changes:
---------------------------------------------------------------------------------------------------
Version: 1.0.0
Date: 2026-08-26
  Features:
    - first release

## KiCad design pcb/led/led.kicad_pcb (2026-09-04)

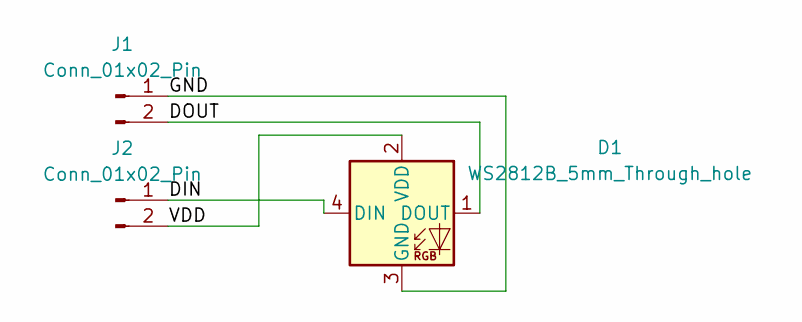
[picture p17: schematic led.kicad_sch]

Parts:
D1: WS2812B_5mm_Through_hole; LED_D5.0mm-4_RGB
J1, J2: Conn_01x02_Pin; PinHeader_1x02_P2.54mm_Horizontal

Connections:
/DIN: D1.4 (DIN), J2.1
/DOUT: D1.1 (DOUT), J1.2
/GND: D1.3 (GND), J1.1
/VDD: D1.2 (VDD), J2.2

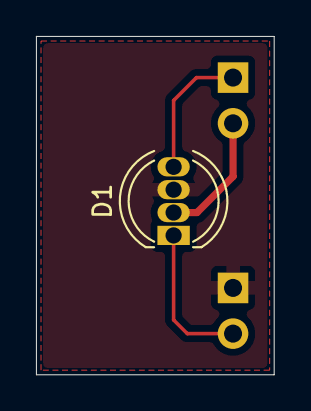
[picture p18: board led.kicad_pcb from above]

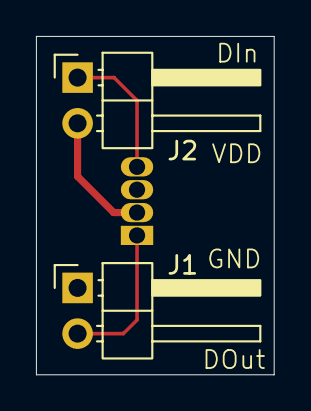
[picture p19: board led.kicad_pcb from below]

Board: 2 copper layers, 13.2 x 18.8 mm, 3 parts (2 on the bottom side), 4 nets.

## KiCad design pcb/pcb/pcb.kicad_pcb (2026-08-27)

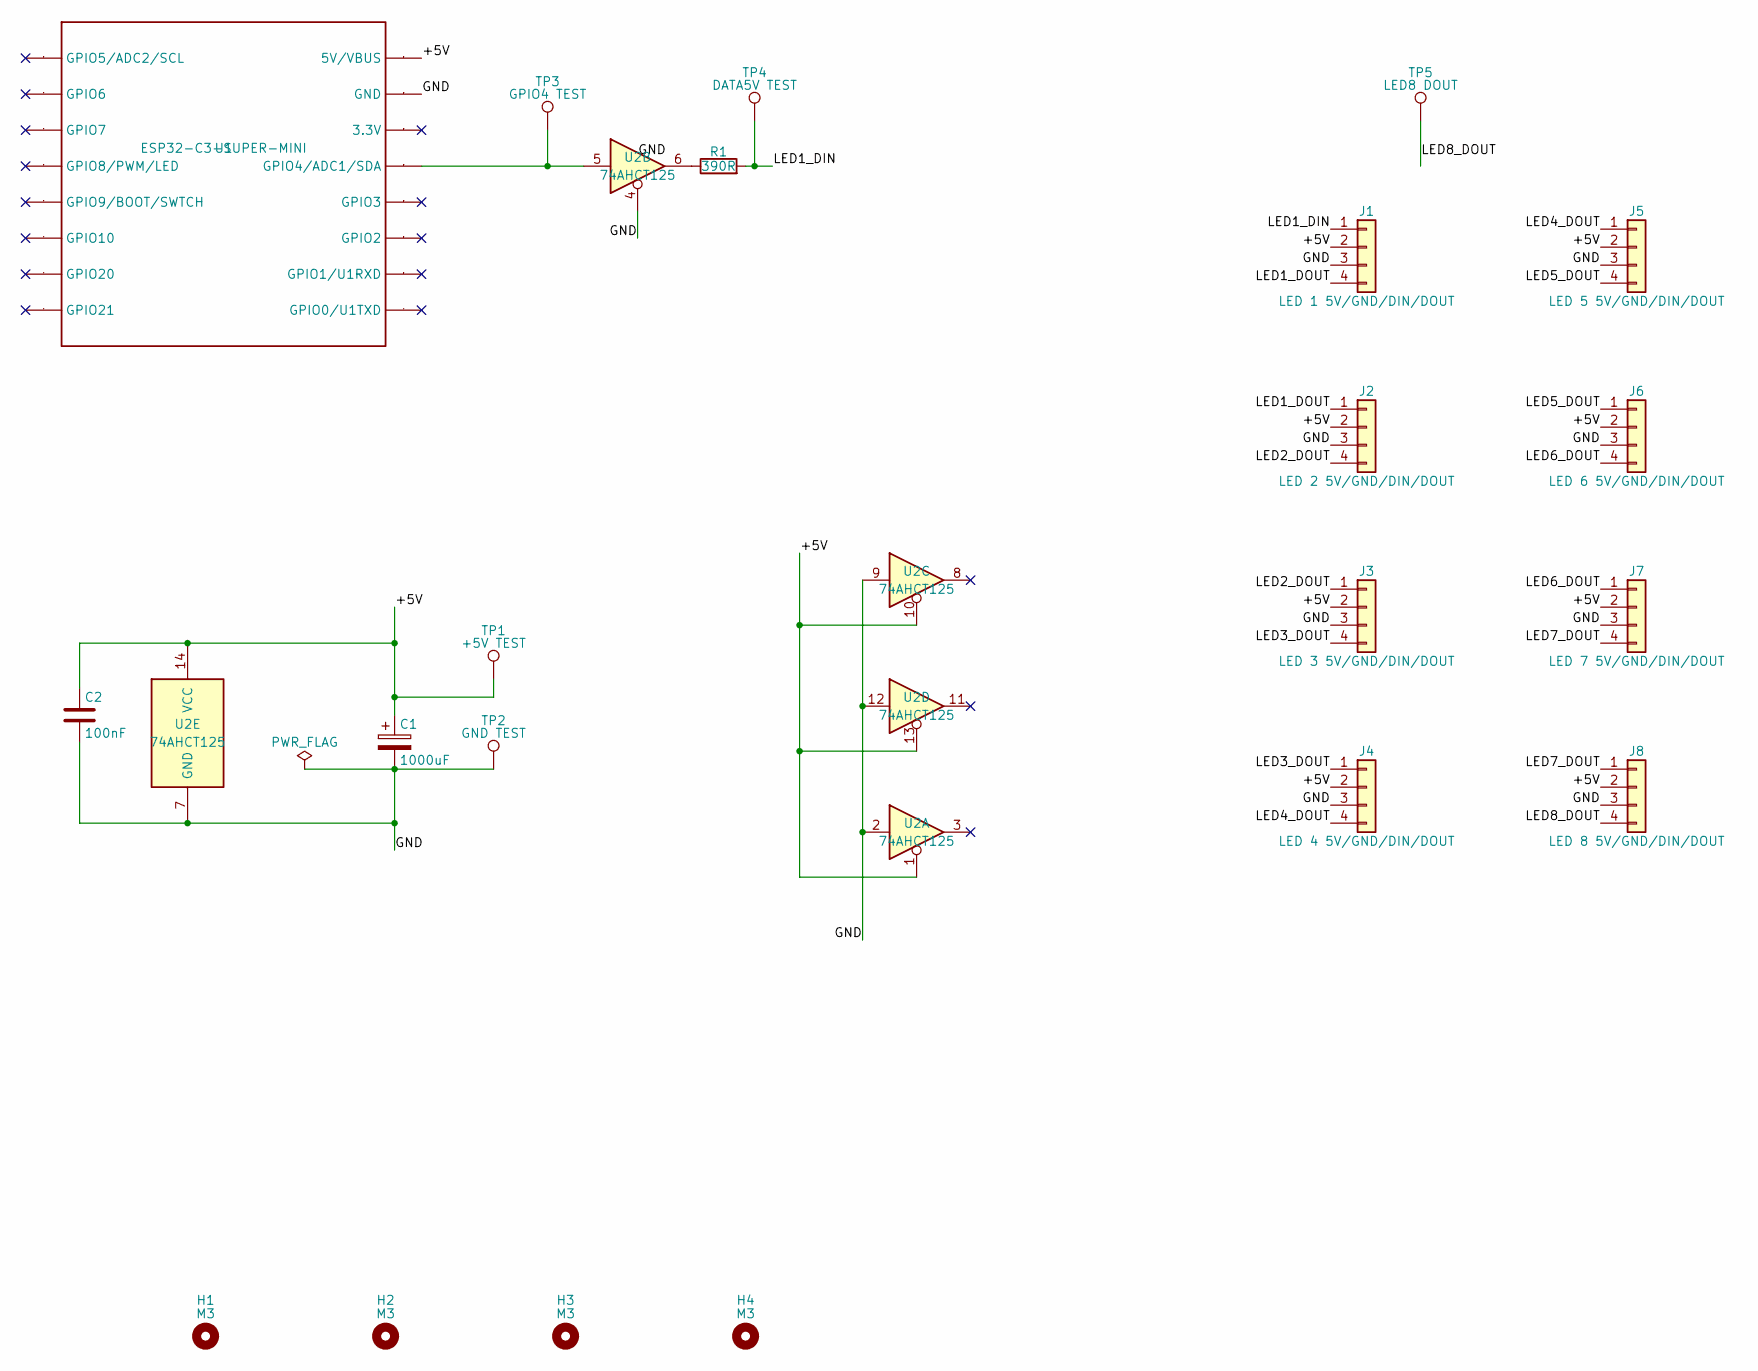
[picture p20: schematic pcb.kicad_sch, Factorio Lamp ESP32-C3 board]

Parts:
C1: 1000uF; CP_Radial_D10.0mm_P5.00mm
C2: 100nF; C_Disc_D5.0mm_W2.5mm_P5.00mm
H1, H2, H3, H4: M3; MountingHole_3.2mm_M3
J1: LED 1 5V/GND/DIN/DOUT; PinHeader_1x04_P2.54mm_Vertical
J2: LED 2 5V/GND/DIN/DOUT; PinHeader_1x04_P2.54mm_Vertical
J3: LED 3 5V/GND/DIN/DOUT; PinHeader_1x04_P2.54mm_Vertical
J4: LED 4 5V/GND/DIN/DOUT; PinHeader_1x04_P2.54mm_Vertical
J5: LED 5 5V/GND/DIN/DOUT; PinHeader_1x04_P2.54mm_Vertical
J6: LED 6 5V/GND/DIN/DOUT; PinHeader_1x04_P2.54mm_Vertical
J7: LED 7 5V/GND/DIN/DOUT; PinHeader_1x04_P2.54mm_Vertical
J8: LED 8 5V/GND/DIN/DOUT; PinHeader_1x04_P2.54mm_Vertical
R1: 390R; R_Axial_DIN0207_L6.3mm_D2.5mm_P10.16mm_Horizontal
TP1: +5V TEST; TestPoint_Plated_Hole_D2.0mm
TP2: GND TEST; TestPoint_Plated_Hole_D2.0mm
TP3: GPIO4 TEST; TestPoint_Plated_Hole_D2.0mm
TP4: DATA5V TEST; TestPoint_Plated_Hole_D2.0mm
TP5: LED8 DOUT; TestPoint_Plated_Hole_D2.0mm
U1: ESP32-C3-SUPER-MINI; ESP32-C3-SUPER-MINI-SOCKET
U2: 74AHCT125; DIP-14_W7.62mm_Socket

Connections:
/+5V: C1.1, C2.1, J1.2, J2.2, J3.2, J4.2, J5.2, J6.2, J7.2, J8.2, TP1.1 (1_1), U1.16 (5V/VBUS), U2.1, U2.10, U2.13, U2.14 (VCC)
/GND: C1.2, C2.2, J1.3, J2.3, J3.3, J4.3, J5.3, J6.3, J7.3, J8.3, TP2.1 (1_1), U1.15 (GND), U2.2, U2.4, U2.7 (GND), U2.9, U2.12
/LED1_DIN: J1.1, R1.2, TP4.1 (1_1)
/LED1_DOUT: J1.4, J2.1
/LED2_DOUT: J2.4, J3.1
/LED3_DOUT: J3.4, J4.1
/LED4_DOUT: J4.4, J5.1
/LED5_DOUT: J5.4, J6.1
/LED6_DOUT: J6.4, J7.1
/LED7_DOUT: J7.4, J8.1
/LED8_DOUT: J8.4, TP5.1 (1_1)
unnamed: R1.1, U2.6
unnamed: TP3.1 (1_1), U1.13 (GPIO4/ADC1/SDA), U2.5

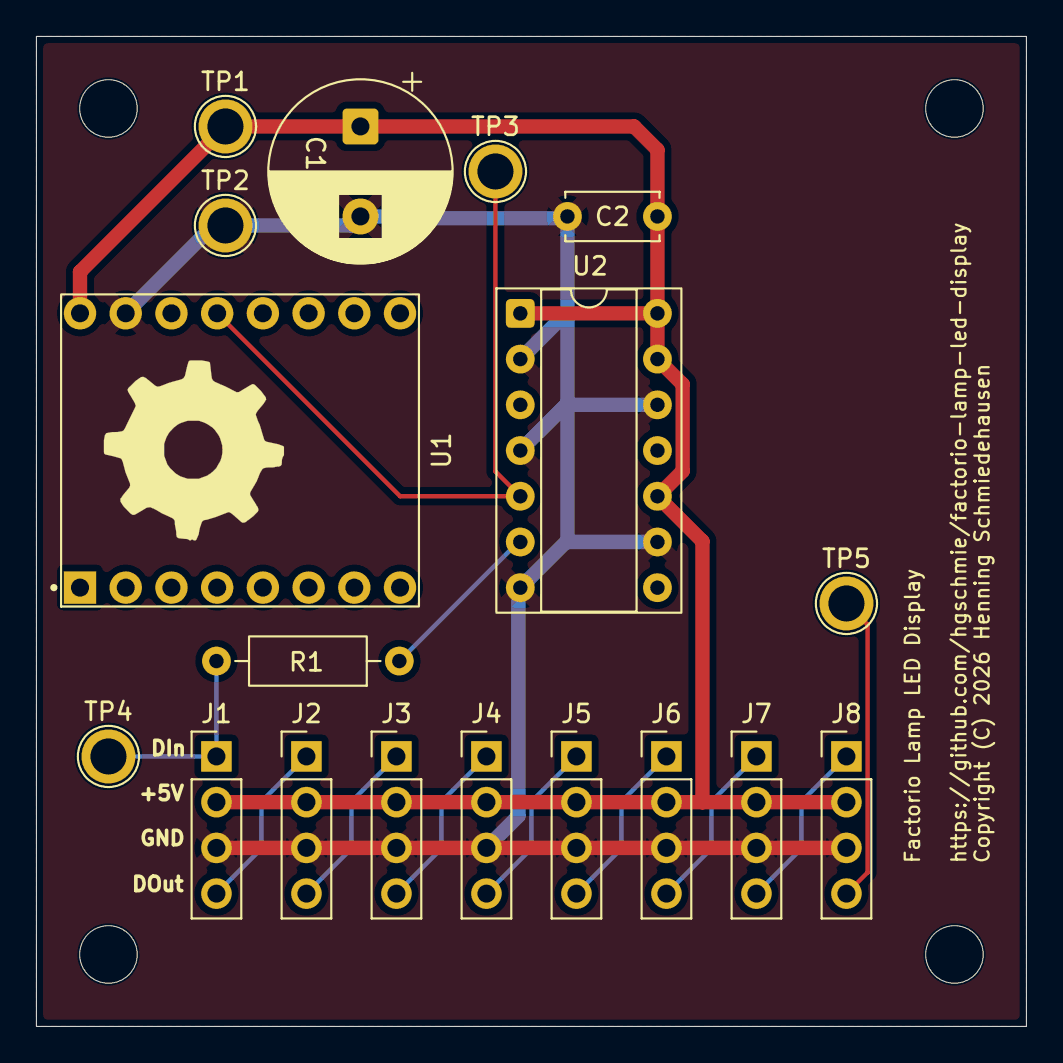
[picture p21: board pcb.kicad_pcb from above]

Board: 2 copper layers, 55.0 x 55.0 mm, 22 parts (0 on the bottom side), 13 nets.

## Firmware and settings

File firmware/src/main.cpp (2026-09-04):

#include <Arduino.h>
#include <Adafruit_NeoPixel.h>
#include <ArduinoJson.h>
#include <ESPmDNS.h>
#include <Preferences.h>
#include <PubSubClient.h>
#include <WebServer.h>
#include <WiFi.h>
#include <WiFiManager.h>
#include <cmath>
#include <string>

#include "ConnectionRecovery.h"
#include "FrameParser.h"

#ifndef FIRMWARE_VERSION
#define FIRMWARE_VERSION "dev"
#endif

constexpr uint8_t DATA_PIN = 4;
constexpr uint8_t BOOT_PIN = 9;
constexpr uint32_t BOOT_HOLD_MS = 5000;
constexpr uint32_t TELEMETRY_MS = 30000;
constexpr uint32_t MQTT_RETRY_MS = 5000;
constexpr uint32_t WIFI_RETRY_MS = 5000;
constexpr uint32_t WIFI_RESTART_MS = 60000;
constexpr uint8_t DEFAULT_PIXEL_COUNT = 8;
constexpr uint8_t DEFAULT_CHANNEL_OFFSET = 0;

struct Settings {
  String broker;
  uint16_t port = 1883;
  String username;
  String password;
  String device;
  String pixelOrder = "RGB";
  uint8_t pixels = DEFAULT_PIXEL_COUNT;
  uint8_t channelOffset = DEFAULT_CHANNEL_OFFSET;
  bool valid() const {
    return broker.length() && port > 0 && device.length() && (pixelOrder == "RGB" || pixelOrder == "GRB") &&
      pixels >= 1 && pixels <= display::kMaxPixels && channelOffset < display::kChannelCount &&
      static_cast<uint16_t>(channelOffset) + pixels <= display::kChannelCount;
  }
};

Preferences preferences;
Settings settings;
WiFiClient wifiClient;
PubSubClient mqtt(wifiClient);
WebServer webServer(80);
Adafruit_NeoPixel* strip = nullptr;
display::Frame frame;
bool haveFrame = false;
uint64_t lastSequence = 0;
uint32_t lastTelemetry = 0;
uint32_t lastMQTTAttempt = 0;
volatile bool portalRequested = false;
String mdnsHostname;
display::WiFiRecovery wifiRecovery(WIFI_RETRY_MS, WIFI_RESTART_MS);

String topic(const char* suffix) { return "factorio-display/v2/device/" + settings.device + "/" + suffix; }
String channelFrameTopic() { return "factorio-display/v2/channels/set"; }

String defaultDeviceID() {
  return "esp-" + String((uint32_t)(ESP.getEfuseMac() & 0xffffff),HEX);
}

bool validDeviceID(const String& value);

void loadSettings() {
  preferences.begin("display", true);
  settings.broker = preferences.getString("broker", ""); settings.port = preferences.getUShort("port", 1883);
  settings.username = preferences.getString("mqtt_user", ""); settings.password = preferences.getString("mqtt_pass", "");
  settings.device = preferences.getString("device", defaultDeviceID()); settings.pixelOrder = preferences.getString("order", "RGB");
  settings.pixels = preferences.getUChar("pixels", DEFAULT_PIXEL_COUNT);
  settings.channelOffset = preferences.getUChar("chan_offset", DEFAULT_CHANNEL_OFFSET);
  preferences.end();
  if (settings.port == 0) settings.port = 1883;
  if (!validDeviceID(settings.device)) settings.device = defaultDeviceID();
  if (settings.pixelOrder != "RGB" && settings.pixelOrder != "GRB") settings.pixelOrder = "RGB";
  if (settings.pixels < 1 || settings.pixels > display::kMaxPixels) settings.pixels = DEFAULT_PIXEL_COUNT;
  if (settings.channelOffset >= display::kChannelCount ||
      static_cast<uint16_t>(settings.channelOffset) + settings.pixels > display::kChannelCount) {
    settings.channelOffset = DEFAULT_CHANNEL_OFFSET;
  }
}

void saveSettings(const Settings& value) {
  preferences.begin("display", false);
  preferences.putString("broker", value.broker); preferences.putUShort("port", value.port);
  preferences.putString("mqtt_user", value.username); preferences.putString("mqtt_pass", value.password);
  preferences.putString("device", value.device); preferences.putString("order", value.pixelOrder);
  preferences.putUChar("pixels", value.pixels);
  preferences.putUChar("chan_offset", value.channelOffset);
  preferences.end();
}

bool validDeviceID(const String& value) {
  if (!value.length() || value.length() > 32) return false;
  for (size_t i = 0; i < value.length(); ++i) {
    const char c = value[i];
    if (!isalnum(static_cast<unsigned char>(c)) && c != '-' && c != '_' && c != '.') return false;
  }
  return true;
}

String htmlEscape(const String& value) {
  String result; result.reserve(value.length() + 16);
  for (size_t i = 0; i < value.length(); ++i) {
    switch (value[i]) {
      case '&': result += "&amp;"; break;
      case '<': result += "&lt;"; break;
      case '>': result += "&gt;"; break;
      case '\"': result += "&quot;"; break;
      case '\'': result += "&#39;"; break;
      default: result += value[i];
    }
  }
  return result;
}

String makeHostname() {
  String result = "factorio-display-" + settings.device;
  result.toLowerCase();
  for (size_t i = 0; i < result.length(); ++i) {
    const char c = result[i];
    if (!isalnum(static_cast<unsigned char>(c)) && c != '-') result.setCharAt(i, '-');
  }
  if (result.length() > 63) result.remove(63);
  return result;
}

void showConfigPage(const String& message = "", int status = 200) {
  String page; page.reserve(5000);
  page = F("<!doctype html><html><head><meta name='viewport' content='width=device-width,initial-scale=1'>"
           "<title>Factorio Display</title><style>body{font:16px system-ui;max-width:34rem;margin:2rem auto;padding:0 1rem;background:#172018;color:#eef7ee}"
           "form{background:#253128;padding:1.25rem;border-radius:.7rem}label{display:block;margin:.8rem 0 .25rem}input,select{box-sizing:border-box;width:100%;padding:.65rem}"
           "button{margin-top:1.2rem;padding:.7rem 1.2rem;background:#65c466;border:0;border-radius:.35rem;font-weight:700}.note{color:#b9c9ba}.message{padding:.7rem;background:#5b3328}</style></head><body>"
           "<h1>Factorio Display</h1><p class='note'>IP: ");
  page += WiFi.localIP().toString(); page += F(" &middot; MQTT: ");
  page += mqtt.connected() ? F("connected") : F("disconnected"); page += F("</p>");
  if (message.length()) { page += F("<p class='message'>"); page += htmlEscape(message); page += F("</p>"); }
  page += F("<form method='post' action='/save'><label>MQTT broker host</label><input required name='broker' value='");
  page += htmlEscape(settings.broker); page += F("'><label>MQTT broker port</label><input required type='number' min='1' max='65535' name='port' value='");
  page += String(settings.port); page += F("'><label>MQTT username</label><input name='username' value='");
  page += htmlEscape(settings.username); page += F("'><label>MQTT password</label><input type='password' name='password' placeholder='Leave blank to keep current password'>"
                                        "<label>Device ID</label><input required maxlength='32' pattern='[A-Za-z0-9._-]+' name='device' value='");
  page += htmlEscape(settings.device); page += F("'><label>Pixel count</label><input required type='number' min='1' max='16' name='pixels' value='");
  page += String(settings.pixels); page += F("'><label>Channel offset</label><input required type='number' min='0' max='63' name='offset' value='");
  page += String(settings.channelOffset); page += F("'><p class='note'>Pixel 0 displays the offset channel; each following pixel displays the next channel.</p>"
                                                   "<label>Pixel color order</label><select name='order'><option value='RGB'");
  if (settings.pixelOrder == "RGB") page += F(" selected");
  page += F(">RGB</option><option value='GRB'");
  if (settings.pixelOrder == "GRB") page += F(" selected");
  page += F(">GRB</option></select><button type='submit'>Save and restart</button></form>"
                                            "<p class='note'>This page is available only on your local network and does not reveal the saved password.</p></body></html>");
  webServer.send(status, "text/html", page);
}

void saveConfigPage() {
  Settings candidate = settings;
  candidate.broker = webServer.arg("broker"); candidate.broker.trim();
  candidate.username = webServer.arg("username"); candidate.username.trim();
  candidate.device = webServer.arg("device"); candidate.device.trim();
  candidate.pixelOrder = webServer.arg("order"); candidate.pixelOrder.toUpperCase();
  const String newPassword = webServer.arg("password");
  if (newPassword.length()) candidate.password = newPassword;
  const long port = webServer.arg("port").toInt();
  const long pixels = webServer.arg("pixels").toInt();
  const long offset = webServer.arg("offset").toInt();
  if (port < 1 || port > 65535 || pixels < 1 || pixels > display::kMaxPixels ||
      offset < 0 || offset >= display::kChannelCount || offset + pixels > display::kChannelCount ||
      !candidate.broker.length() || !validDeviceID(candidate.device) ||
      (candidate.pixelOrder != "RGB" && candidate.pixelOrder != "GRB")) {
    showConfigPage("Invalid values. Check the broker, port, device ID, pixel count, and channel offset.", 400); return;
  }
  candidate.port = static_cast<uint16_t>(port); candidate.pixels = static_cast<uint8_t>(pixels); candidate.channelOffset = static_cast<uint8_t>(offset);
  saveSettings(candidate);
  webServer.send(200, "text/html", "<!doctype html><html><head><meta name='viewport' content='width=device-width,initial-scale=1'>"
                                     "<meta http-equiv='refresh' content='10;url=/'>"
                                     "<title>Factorio Display</title></head><body><p>Saved. Restarting&hellip;</p>"
                                     "<p>This page will return to the display settings in 10 seconds.</p></body></html>");
  delay(300); ESP.restart();
}

void startMDNS() {
  MDNS.end();
  mdnsHostname = makeHostname();
  if (MDNS.begin(mdnsHostname.c_str())) MDNS.addService("http", "tcp", 80);
}

void startConfigServer() {
  startMDNS();
  webServer.on("/", HTTP_GET, [](){ showConfigPage(); });
  webServer.on("/save", HTTP_POST, saveConfigPage);
  webServer.onNotFound([](){ webServer.sendHeader("Location", "/"); webServer.send(302); });
  webServer.begin();
  Serial.printf("Configuration page: http://%s/ or http://%s.local/\n", WiFi.localIP().toString().c_str(), mdnsHostname.c_str());
}

bool runPortal(bool force = false) {
  WiFiManager wm;
  wm.setConfigPortalTimeout(300);
  const String ap = "Factorio-Display-" + String((uint32_t)(ESP.getEfuseMac() & 0xffffff),HEX);
  return force ? wm.startConfigPortal(ap.c_str()) : wm.autoConnect(ap.c_str());
}

void mqttCallback(char*, byte* payload, unsigned int length) {
  display::Frame candidate; std::string error;
  if (!display::parseFrame(reinterpret_cast<char*>(payload),length,settings.pixels,settings.channelOffset,lastSequence,millis(),candidate,error)) {
    Serial.printf("Rejected MQTT frame: %s\n",error.c_str()); return;
  }
  frame=candidate;lastSequence=frame.sequence;haveFrame=true;
}

void publishAvailability(const char* value) { mqtt.publish(topic("availability").c_str(),value,true); }

bool connectMQTT() {
  if (mqtt.connected()) return true;
  const String clientId="factorio-display-"+settings.device;
  const String availability=topic("availability");
  if (!mqtt.connect(clientId.c_str(),settings.username.c_str(),settings.password.c_str(),availability.c_str(),1,true,"offline")) {
    Serial.printf("MQTT connection failed (state %d); retrying in 5 seconds\n", mqtt.state()); return false;
  }
  // A reconnect begins a new ordered delivery session. This permits the broker's
  // retained frame (and a restarted daemon's sequence) to restore the display.
  lastSequence=0;haveFrame=false;
  if (!mqtt.subscribe(channelFrameTopic().c_str(),1)) {
    Serial.println("MQTT subscription failed; retrying in 5 seconds"); mqtt.disconnect(); return false;
  }
  publishAvailability("online");
  Serial.printf("MQTT connected to %s:%u as %s\n",settings.broker.c_str(),settings.port,clientId.c_str());
  return true;
}

void publishTelemetry() {
  JsonDocument doc;doc["version"]=1;doc["firmware"]=FIRMWARE_VERSION;doc["ip"]=WiFi.localIP().toString();
  doc["rssi"]=WiFi.RSSI();doc["uptime_s"]=millis()/1000;doc["pixel_count"]=settings.pixels;
  doc["channel_offset"]=settings.channelOffset;
  doc["pixel_order"]=settings.pixelOrder;
  char payload[256];const size_t n=serializeJson(doc,payload,sizeof(payload));
  mqtt.publish(topic("telemetry").c_str(),reinterpret_cast<const uint8_t*>(payload),n,false);
}

uint8_t scale(uint8_t value,float amount){return static_cast<uint8_t>(value*amount);}
void render() {
  if (!strip) return;
  const uint32_t now=millis();
  const auto state=display::renderState(mqtt.connected(),haveFrame,frame,now);
  if (state==display::RenderState::MqttDisconnected) {
    const float wave=(sinf(now/700.0f)+1.0f)*0.5f;strip->setBrightness(display::kMaxBrightness);
    for(uint8_t i=0;i<settings.pixels;i++)strip->setPixelColor(i,strip->Color(scale(255,wave),scale(90,wave),0));strip->show();return;
  }
  if (state==display::RenderState::AwaitingFrame) {
    strip->clear();strip->show();return;
  }
  strip->setBrightness(display::kMaxBrightness);
  const bool blink=(now/500)%2==0;const float pulse=(sinf(now/700.0f)+1.0f)*0.5f;
  for(uint8_t i=0;i<frame.pixelCount;i++){
    const auto& p=frame.pixels[i];float amount=p.brightness/255.0f;if(p.effect==display::Effect::Blink)amount*=blink?1.0f:0.0f;else if(p.effect==display::Effect::Pulse)amount*=pulse;
    strip->setPixelColor(i,strip->Color(scale(p.r,amount),scale(p.g,amount),scale(p.b,amount)));
  }
  strip->show();
}

void monitorBootButton(void*) {
  uint32_t pressedAt = 0;
  for (;;) {
    if (digitalRead(BOOT_PIN) == LOW) {
      if (!pressedAt) pressedAt = millis();
      else if (millis() - pressedAt >= BOOT_HOLD_MS) portalRequested = true;
    } else pressedAt = 0;
    vTaskDelay(pdMS_TO_TICKS(20));
  }
}

void logWiFiEvent(WiFiEvent_t event, WiFiEventInfo_t info) {
  if (event == ARDUINO_EVENT_WIFI_STA_DISCONNECTED) {
    Serial.printf("Wi-Fi disconnected (reason %u)\n",info.wifi_sta_disconnected.reason);
  }
}

void setup() {
  Serial.begin(115200);pinMode(BOOT_PIN,INPUT_PULLUP);
  xTaskCreate(monitorBootButton,"boot-button",2048,nullptr,1,nullptr);
  WiFi.onEvent(logWiFiEvent);
  loadSettings();
  while(true){
    const bool forcePortal=portalRequested;
    if(forcePortal){portalRequested=false;Serial.println("BOOT held for five seconds; forcing captive portal");}
    if(runPortal(forcePortal))break;
    Serial.println("Wi-Fi provisioning failed; retrying");delay(1000);
  }
  WiFi.setAutoReconnect(true);
  WiFi.setSleep(false);
  wifiRecovery.markConnected();
  Serial.printf("Wi-Fi connected: %s (RSSI %d dBm)\n",WiFi.localIP().toString().c_str(),WiFi.RSSI());
  const neoPixelType pixelType=(settings.pixelOrder=="GRB"?NEO_GRB:NEO_RGB)+NEO_KHZ800;
  strip=new Adafruit_NeoPixel(settings.pixels,DATA_PIN,pixelType);strip->begin();strip->clear();strip->show();
  mqtt.setServer(settings.broker.c_str(),settings.port);mqtt.setCallback(mqttCallback);mqtt.setBufferSize(8192);mqtt.setKeepAlive(30);mqtt.setSocketTimeout(2);
  startConfigServer();
  if(!settings.valid()||!validDeviceID(settings.device))Serial.println("MQTT is not configured; use the management page");
}

void loop() {
  if(portalRequested){Serial.println("BOOT held for five seconds; starting captive portal");webServer.stop();MDNS.end();if(mqtt.connected()){publishAvailability("offline");mqtt.disconnect();}runPortal(true);ESP.restart();}
  webServer.handleClient();
  if(WiFi.status()!=WL_CONNECTED){
    const bool newlyDisconnected=!wifiRecovery.recovering();
    const auto action=wifiRecovery.updateDisconnected(millis());
    if(newlyDisconnected){Serial.println("Wi-Fi unavailable; stopping MQTT transport");wifiClient.stop();haveFrame=false;}
    if(action==display::WiFiRecoveryAction::Reconnect){Serial.println("Attempting Wi-Fi reconnect");WiFi.reconnect();}
    else if(action==display::WiFiRecoveryAction::Restart){Serial.println("Wi-Fi unavailable for 60 seconds; restarting");delay(50);ESP.restart();}
    render();delay(10);return;
  }
  if(wifiRecovery.markConnected()){
    Serial.printf("Wi-Fi restored: %s (RSSI %d dBm)\n",WiFi.localIP().toString().c_str(),WiFi.RSSI());
    wifiClient.stop();lastMQTTAttempt=0;startMDNS();
  }
  if(settings.valid()&&validDeviceID(settings.device)&&!mqtt.connected()&&(lastMQTTAttempt==0||millis()-lastMQTTAttempt>=MQTT_RETRY_MS)){lastMQTTAttempt=millis();connectMQTT();}
  if(mqtt.connected()&&!mqtt.loop())Serial.printf("MQTT connection lost (state %d)\n",mqtt.state());
  if(mqtt.connected()&&millis()-lastTelemetry>=TELEMETRY_MS){lastTelemetry=millis();publishTelemetry();}
  render();delay(10);
}

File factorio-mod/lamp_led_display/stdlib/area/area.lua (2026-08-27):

--- Tools for working with bounding boxes.
---@class Area.Area: BoundingBox.struct
---@field left_top MapPosition
---@field right_bottom MapPosition
---@field left_bottom? MapPosition
---@field right_top? MapPosition
---@field orientation? number
local Area = { __class = 'Area', __index = require('stdlib.core') }
setmetatable(Area, Area)

package.loaded['__' .. script.mod_name .. '__/' .. (...):gsub('%.', '/') .. '.lua'] = Area

local Position = require('stdlib.area.position')

local math = require('stdlib.utils.math')
local string = require('stdlib.utils.string')
local abs, floor, max = math.abs, math.floor, math.max

local metatable

--- Constructor Methods
-- @section Constructors

Area.__call = function(_, ...)
    local type = type((...))
    if type == 'table' then
        local t = (...)
        if t.left_top and t.right_bottom then
            return Area.load(...)
        else
            return Area.new(...)
        end
    elseif type == 'string' then
        return Area.from_string(...)
    else
        return Area.construct(...)
    end
end

local function new_area(lt, rb, o)
    return setmetatable({ left_top = lt, right_bottom = rb, orientation = o }, metatable)
end

--- Converts an area in either array or table format to an area with a metatable.
-- Returns itself if it already has a metatable
---@param area BoundingBox the area to convert
---@return BoundingBox area a converted area
function Area.new(area)
    local left_top = Position.new(area.left_top or area[1])
    local right_bottom = Position.new(area.right_bottom or area[2] or area[1])
    return setmetatable({ left_top = left_top, right_bottom = right_bottom, orientation = area.orientation }, metatable)
end

--- Creates an area from number parameters.
---@param ... number x1, y1, x2, and y2 coordinates
---@return BoundingBox area the area in table format
function Area.construct(...)
    local args = type((...)) == 'table' and { select(2, ...) } or { select(1, ...) }

    local lt = Position.construct_xy(args[1] or 0, args[2] or 0)
    local rb = Position.construct_xy(args[3] or lt.x, args[4] or lt.y)

    return setmetatable({ left_top = lt, right_bottom = rb }, metatable)
end

--- Loads the metatable into the passed Area without creating a new one.
---@param area BoundingBox the Area to set the metatable onto
---@return BoundingBox area the area with its metatable attached
function Area.load(area)
    area.left_top = Position.load(area.left_top)
    area.right_bottom = Position.load(area.right_bottom)
    return setmetatable(area, metatable)
end

--- Converts an area string to an area.
---@param area_string string the area to convert
---@return BoundingBox
function Area.from_string(area_string)
    return Area(load('return ' .. area_string)())
end

--- Converts a string key area to an area.
---@param area_string string the area to convert
---@return BoundingBox
function Area.from_key(area_string)
    local tab = string.split(area_string, ',', false, tonumber)
    local lt = Position.new { x = tab[1], y = tab[2] }
    local rb = Position.new { x = tab[3], y = tab[4] }
    return new_area(lt, rb)
end

--- Area Methods
-- @section Methods

--- Stores the area for recall later, not deterministic.
-- Only the last area stored is saved.
---@param area BoundingBox
function Area.store(area)
    rawset(getmetatable(area), '_saved', area)
    return area
end

--- Recalls the stored area.
---@param area BoundingBox
---@return BoundingBox area the stored area
function Area.recall(area)
    return rawget(getmetatable(area), '_saved')
end

--- Normalizes the given area.
-- <ul>
-- <li>Swaps the values between `right_bottom.x` & `left_top.x` **IF** `right_bottom.x` < `left_top.x`
-- <li>Swaps the values between `right_bottom.y` & `left_top.y` **IF** `right_bottom.y` < `left_top.y`
-- </ul>
---@param area BoundingBox the area to normalize
---@return BoundingBox area a new normalized area
function Area.normalize(area)
    local left_top = Position.new(area.left_top)
    local right_bottom = Position.new(area.right_bottom)
    ---@cast left_top MapPosition.struct
    ---@cast right_bottom MapPosition.struct

    if right_bottom.x < left_top.x then left_top.x, right_bottom.x = right_bottom.x, left_top.x end
    if right_bottom.y < left_top.y then left_top.y, right_bottom.y = right_bottom.y, left_top.y end

    return new_area(left_top, right_bottom, area.orientation)
end

--- Normalize an area in place.
---@param area BoundingBox the area to normalize
---@return BoundingBox area the area normalized in place
function Area.normalized(area)
    local lt, rb = area.left_top, area.right_bottom
    if rb.x < lt.x then lt.x, rb.x = rb.x, lt.x end
    if rb.y < lt.y then lt.y, rb.y = rb.y, lt.y end
    return area
end

--- Convert area from pixels.
---@param area BoundingBox
---@return BoundingBox
function Area.from_pixels(area)
    return new_area(Position.from_pixels(area.left_top), Position.from_pixels(area.right_bottom), area.orientation)
end

--- Convert area to pixels.
---@param area BoundingBox
---@return BoundingBox
function Area.to_pixels(area)
    return new_area(Position.to_pixels(area.left_top), Position.to_pixels(area.right_bottom), area.orientation)
end

--- Rounds an areas points to its closest integer.
---@param area BoundingBox
---@return BoundingBox
function Area.round(area)
    return new_area(Position.round(area.left_top), Position.round(area.right_bottom), area.orientation)
end

--- Ceils an area by increasing the size of the area outwards
---@param area BoundingBox the area to round
---@return BoundingBox
function Area.ceil(area)
    return new_area(Position.floor(area.left_top), Position.ceil(area.right_bottom), area.orientation)
end

--- Floors an area by decreasing the size of the area inwards.
---@param area BoundingBox the area to round
---@return BoundingBox
function Area.floor(area)
    return new_area(Position.ceil(area.left_top), Position.floor(area.right_bottom), area.orientation)
end

-- When looking for tile center points, look inwards on right bottom
-- when x or y is int. This will keep the area with only the tiles it
-- contains.
local function right_bottom_center(pos)
    local x, y
    local fx, fy = floor(pos.x), floor(pos.y)
    x = fx == pos.x and (fx - 0.5) or (fx + 0.5)
    y = fy == pos.y and (fy - 0.5) or (fy + 0.5)
    return Position.construct_xy(x, y)
end

--- Gets the center positions of the tiles where the given area's two positions reside.
---@param area BoundingBox
---@return BoundingBox area the area with its two positions at the center of their tiles
function Area.center_points(area)
    return new_area(Position.center(area.left_top), right_bottom_center(area.right_bottom), area.orientation)
end
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

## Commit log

2026-08-21 initial import
    [factorio-status-display.cfg]
2026-08-23 version 2.0
    [bom.csv, designators.csv, factorio-status-display.cfg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]
2026-08-27 Rebuild Factorio mod
    - use framework / stdlib
    - make code nicer
    - remove most of the codex written pieces
    [base.cfg, factorio-status-display.cfg, settings.cfg]
2026-08-27 rename mod folder
    [base.cfg, settings.cfg]
2026-08-27 add 3d print files
    [Factorio Lamp - PETG.3mf, Factorio Lamp - PLA.3mf]
2026-08-27 update pcb files
    [pcb.kicad_pcb, pcb.kicad_sch]
2026-08-28 update pcb production files
    [designators.csv]
2026-08-28 remove unneeded pcb files
    [bom.csv, designators.csv, positions.csv]
2026-08-28 add pcb readme
2026-08-28 add pcb image
2026-08-28 add board preview
2026-09-04 fix firmware wlan reconnect bug
    [main.cpp]
2026-09-04 add led pcb board
    [bom.csv, designators.csv, led.kicad_pcb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]
2026-09-04 add a case for the controller board
    [board_data.scad, case.scad]
2026-09-04 Redesign case lid with V groove and full-width bar
    The printed lid of the controller-board case was very tight and the
    slicer filled the lid grooves with support that was almost impossible
    to remove. Both came from the rectangular groove, whose flat ceiling is
    a 1.4 mm horizontal overhang along the side and front walls.
    The groove is now a V with both flanks at 45 degrees; the lid's left,
    right and front edges are chamfered top and bottom to a matching V with
    a 0.4 mm tip flat. The groove is the lid profile grown by lid_clear on
    every face, so the lid centres itself and nothing on either part needs
    support. Both profiles are hulls of thin slabs, giving mitred corners.
    The inner-width rear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
    [case.scad]
2026-09-04 Fix case screw pilots for M3 self-tapping
    M3 screws would not drive into the standoffs of the printed case; only
    M2 fitted, and loosely. The pilot was modelled at 2.5 mm with no
    allowance for FDM cutting vertical holes undersized by roughly 0.2 to
    0.3 mm, so it printed near 2.2 mm. That is below the minor diameter of
    an M3 and well above an M2 major diameter, which matches both symptoms.
    screw_hole_d now means the diameter measured on the finished print, and
    the new hole_comp is added to it in screw_hole_model, which is what the
    model cuts. A new assert fails the build if the wall left around the
    pilot drops below 1.2 mm, since a thread-forming screw splits a thinner
    boss. Nothing else abou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
    [case.scad]
2026-09-21 add baseplate
    [Factorio Lamp - PETG.3mf, Factorio Lamp - PLA.3mf, check-alternative-clearance.scad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]
2026-09-21 fix relative pathes
    [check-clearance.scad, inspect.scad, lamp-base-plate-alternative.scad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]
2026-09-21 update docs
    [wire-connector.stl]
2026-10-12 framework RELEASE_4
    Sync framework and stdlib from core_libs RELEASE_4 (8fa88b0f8271d07b6b27725bd977c24d4bb0c5a9).
